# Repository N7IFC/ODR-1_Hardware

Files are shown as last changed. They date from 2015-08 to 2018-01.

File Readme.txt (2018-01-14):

This is the hardware repository for the ODR-1 (Open Design Radio - 1) which is a stand-alone "Firmware" defined QRP transceiver.The design goal for the radio is to cover from 1.8MHz (160 meters) up to 50 MHz (6 meters) though it may be able to cover up to 70MHz (4 meters).

The ODR-1 radio consists of the following circuit boards:

1) Display Board
2) Processor Board
3) Oscillator & Mixer Board
4) Amp and tuner board (not released, under design)

Each board hardware revision will have its own directory. When the circuit board layout changes significantly, there is a letter revision. If a minor revision occurs, such as a component value change or a cut and add, then a numeric suffix will be added to the letter revision. this allows older boards to be modified while not impacting the release of new board designs.

All schematic capture and layout is done with stable releases of KiCAD. You are encouraged to support the KiCAD development team as it is an outstanding collection of software.

Hardware - https://github.com/N7IFC/ODR-1_Hardware
Firmware - https://github.com/sylvanwilliams/ODR-1_Firmware

73s!

Bill N7IFC

This work is licensed under the Creative Commons Attribution-ShareAlike 4.0 International License.To view a copy of this license, visit http://creativecommons.org/licenses/by-sa/4.0/ or send a letter to Creative Commons, PO Box 1866, Mountain View, CA 94042, USA.

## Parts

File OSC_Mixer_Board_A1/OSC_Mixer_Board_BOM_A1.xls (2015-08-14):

Id | Designator | Package | Quantity | Designation | Description | MFR1 P/N | MFR1 Digikey P/N | MFR1 Mouser P/N | MFR1 Price | MFR1 Ext Price | MFR2 P/N | MFR2 Digikey P/N | MFR2 Price
1 | PCB |  | 1 |  | Bare Circuit Board |  |  |  | $75.00 | $75.00
2 | C17,C15 | SM0805-1 | 2 | 56pF | CAP CER 56PF 50V 5% NP0 0805 | C0805C560J5GACTU | 399-1118-1-ND |  | $0.10 | $0.20
3 | C79,C80 | SM0805-1 | 2 | 100pF | CAP CER 100PF 50V 5% NP0 0805 | CL21C101JBANNNC | 1276-1014-1-ND |  | $0.10 | $0.20
4 | C19,C23 | SM0805-1 | 2 | 120pF | CAP CER 120PF 50V 5% NP0 0805 | C0805C121J5GACTU | 399-1124-1-ND |  | $0.10 | $0.20
5 | C28,C24 | SM0805-1 | 2 | 130pF | CAP CER 130PF 100V 5% NP0 0805 | GRM2165C2A131JA01D | 490-1602-1-ND |  | $0.17 | $0.34
6 | C14, C18, C22,C20 | SM0805-1 | 4 | 150pF | CAP CER 150PF 50V 5% NP0 0805 | C0805C151J5GACTU | 399-1125-1-ND |  | $0.10 | $0.40
7 | C29,C33 | SM0805-1 | 2 | 180pF | CAP CER 180PF 50V 5% NP0 0805 | CL21C181JBANNNC | 1276-1129-1-ND |  | $0.11 | $0.22
8 | C27,C25 | SM0805-1 | 2 | 200pF | CAP CER 200PF 100V 5% NP0 0805 | GRM2165C2A201JA01D | 490-1606-1-ND |  | $0.17 | $0.34
9 | C21 | SM0805-1 | 1 | 220pF | CAP CER 220PF 50V 5% NP0 0805 | C0805C221J5GACTU | 399-1127-1-ND |  | $0.10 | $0.10
10 | C112,C113,C103,C106,C109,C110,C26,C34,C38 | SM0805-1 | 9 | 240pF | CAP CER 240PF 100V 5% NP0 0805 | GRM2165C2A241JA01D | 490-1608-1-ND |  | $0.14 | $1.27
11 | C16,C32,C30 | SM0805-1 | 3 | 300pF | CAP CER 300PF 50V 5% NP0 0805 | C0805C301J5GACTU | 399-9220-1-ND |  | $0.31 | $0.93
12 | C31,C39,C43 | SM0805-1 | 3 | 360pF | CAP CER 360PF 50V 5% NP0 0805 | C0805C361J5GACTU | 399-9230-1-ND |  | $0.31 | $0.93
13 | C37,C35 | SM0805-1 | 2 | 430pF | CAP CER 430PF 50V 5% NP0 0805 | CL21C431JBANNNC | 1276-2659-1-ND |  | $0.10 | $0.20
14 | C93,C94,C99,C98,C36 | SM0805-1 | 5 | 470pF | CAP CER 470PF 50V 5% NP0 0805 | CL21C471JBANNNC | 1276-1121-1-ND |  | $0.11 | $0.55
15 | C44,C48, C42,C40 | SM0805-1 | 4 | 620pF | CAP CER 620PF 50V 5% NP0 0805 | CL21C621JBCNNNC | 1276-2677-1-ND |  | $0.10 | $0.40
16 | C41 | SM0805-2 | 1 | 750pF | CAP CER 750PF 50V 5% NP0 0805 | C0805C751J5GACTU | 399-9271-1-ND |  | $0.37 | $0.37
17 | C47,C45,C49,C53 | SM0805-1 | 4 | 1100pF | CAP CER 1100PF 50V 5% NP0 0805 | GRM2165C1H112JA01D | 490-1623-1-ND |  | $0.18 | $0.72
18 | C46 | SM0805-1 | 1 | 1300pF | CAP CER 1300PF 50V 5% NP0 0805 | GRM2165C1H132JA01D | 490-1624-1-ND |  | $0.19 | $0.19
19 | C52,C50 | SM0805-1 | 2 | 2000pF | CAP CER 2000PF 100V 5% NP0 0805 | GRM2165C2A202JA01D | 490-6447-1-ND |  | $0.22 | $0.44
20 | C51 | SM0805-1 | 1 | 2200pF | CAP CER 2200PF 50V 5% NP0 0805 | CL21C222JBFNNNE | 1276-2993-1-ND |  | $0.17 | $0.17
21 | C102,C105 | SM0805-1 | 2 | 2400pF | CAP CER 2400PF 50V 5% NP0 0805 | GRM2165C1H242JA01D | 490-1629-1-ND |  | $0.22 | $0.44
22 | C73,C69,C66 | SM0805-1 | 3 | 0.01uF | CAP CER 10000PF 100V X7R 0805 | CL21B103KC65PNC | 1276-2440-1-ND |  | $0.10 | $0.30
23 | C96,C91,C97,C92 | SM0805-1 | 4 | 0.022uF | CAP CER 0.022UF 50V 5% C0G 0805 | CGA4J2C0G1H223J125AA | 445-6949-1-ND |  | $0.33 | $1.32
24 | C88,C87,C86,C83,C85,C57,C58,C114,C116,C115,C117,C118,C119,C120,C95,C100 | SM0805-1 | 16 | 0.033uF | CAP CER 0.033UF 100V 5% C0G 0805 | CGA4J1C0G2A333J125AC | 445-172691-1-ND |  | $0.33 | $5.28
25 | C77,C90,C89,C101,C104,C78,C71,C75,C81,C82,C76,C108,C107,C111,C5,C9,C1,C2,C11,C10,C12,C13,C64,C68,C67,C59,C60,C61,C62,C63,C54,C56 | SM0805-1 | 32 | 0.1uF | CAP CER 0.1UF 100V 10% X7R 0805 | CL21B104KCC5PNC | 1276-2447-1-ND |  | $0.11 | $3.52
26 | C70,C65 | SM0805-1 | 2 | 0.33uF | CAP CER 0.33UF 50V 10% X7R 0805 | CL21B334KBFNNNE | 1276-1123-1-ND |  | $0.18 | $0.36
27 | C8 | SM0805-1 | 1 | 1uF | CAP CER 1UF 50V 10% X7R 0805 | CL21B105KBFNNNE | 1276-1029-1-ND |  | $0.26 | $0.26
28 | C74,C72, C55 | SM0805-1 | 3 | 4.7uF | CAP CER 4.7UF 10V 10% X7R 0805 | CL21B475KPFNNNE | 1276-2972-1-ND |  | $0.20 | $0.60
29 | C4,C3,C6 | CAP_8.3X8.3 | 3 | 39uF | CAP POLYMER 39UF 20% 35V SMD | 35SVPF39M | P16561CT-ND |  | $1.68 | $5.04
30 | C84,C7 | CAP_8.3X8.3 | 2 | 270uF | CAP POLYMER 270UF 20% 16V SMD | 16SVPF270M | P16480CT-ND |  | $1.71 | $3.42
31 | D1 | DO-214AB(SMC) | 1 | SMCJ20CA | TVS DIODE 20VWM 32.4VC SMC | SMCJ20CA | SMCJ20CAFSCT-ND |  | $0.58 | $0.58
32 | D2 | DO-214AB(SMC) | 1 | SSC54-E3 | DIODE SCHOTTKY 40V 5A DO214AB | SSC54-E3/9AT | SSC54-E3/9ATGICT-ND |  | $0.63 | $0.63
33 | D10,D9,D8,D7,D6,D5,D4,D3 | SOD123 | 8 | 1N4148 | DIODE GEN PURP 100V 300MA SOD123 | 1N4148W-7-F | 1N4148W-FDICT-ND |  | $0.17 | $1.36
34 | FB1,FB2 | SM0805-1 | 2 | MPZ2012S101AT000 | FERRITE CHIP 100 OHM 4A 0805 | MPZ2012S101AT000 | 445-1567-1-ND |  | $0.12 | $0.24
35 | FB4,FB6,FB3,FB5 | SM0805-1 | 4 | MPZ2012S331A | FERRITE CHIP 330 OHM 2.5A 0805 | MPZ2012S331AT000 | 445-1569-1-ND |  | $0.12 | $0.48
36 | J1 | SIL-10 | 1 | FM-10 | CONN HEADER FMALE 10POS .1" GOLD | PPPC101LFBN-RC | S7043-ND |  | $0.84 | $0.84
37 | J2,J3,J4,J5,J6,J7 | SIL-12 | 6 | FM-12 | CONN HEADER FMALE 12POS .1" GOLD | PPPC121LFBN-RC | S7045-ND |  | $1.01 | $6.06
38 | J8 | PWR_JACK_5.5x2.1mm | 1 | PJ-057AH | CON PWR JCK 2.0 X 6.3MM HIGH CUR | PJ-057AH | CP-057AH-ND |  | $1.19 | $1.19
39 | L29,L35 | SM1210 | 2 | 0.033uH | FIXED IND 33NH 450MA 240 MOHM | NLV32T-033J-PF |  | 810-NLV32T-033J | $0.27 | $0.54
40 | L33,L32,L31,L30 | SM1210 | 4 | 0.056uH | FIXED IND 56NH 450MA 330 MOHM | NLV32T-056J-EF |  | 810-NLV32T-056J-EF | $0.27 | $1.08
41 | L1 | SM1210 | 1 | 0.082uH | FIXED IND 82NH 450MA 400 MOHM | NLV32T-082J-PF |  | 810-NLV32T-082J-PF | $0.27 | $0.27
42 | L28 | SM1210 | 1 | 0.10uH | FIXED IND 100NH 450MA 440 MOHM | NLV32T-R10J-PF |  | 810-NLV32T-R10J | $0.27 | $0.27
43 | L2 | SM1210 | 1 | 0.150uH | FIXED IND 150NH 450MA 250 MOHM | NLV32T-R15J-PF |  | 810-NLV32T-R15J | $0.27 | $0.27
44 | L3,L5,L4 | SM1210 | 3 | 0.22uH | FIXED IND 220NH 450MA 320 MOHM | NLV32T-R22J-PF |  | 810-NLV32T-R22J | $0.27 | $0.81
45 | L7,L8,L6 | SM1210 | 3 | 0.56uH | FIXED IND 560NH 450MA 550 MOHM | NLV32T-R56J-PF |  | 810-NLV32T-R56J-PF | $0.27 | $0.81
46 | L9,L11,L10 | SM1210 | 3 | 0.82uH | FIXED IND 820NH 450MA 650 MOHM | NLV32T-R82J-PF |  | 810-NLV32T-R82J-PF | $0.27 | $0.81
47 | L12,L14,L13 | SM1210 | 3 | 1.2uH | FIXED IND 1.2UH 390MA 750 MOHM | NLV32T-1R2J-PF |  | 810-NLV32T-1R2J-PF | $0.27 | $0.81
48 | L16,L17,L15 | SM1210 | 3 | 1.8uH | FIXED IND 1.8UH 350MA 900 MOHM | NLV32T-1R8J-PF |  | 810-NLV32T-1R8J-PF | $0.27 | $0.81
49 | L19,L20,L18 | SM1210 | 3 | 2.7uH | FIXED IND 2.7UH 290MA 1.1 OHM | NLV32T-2R7J-PF |  | 810-NLV32T-2R7J-PF | $0.27 | $0.81
50 | L22,L23,L21 | SM1210 | 3 | 3.9uH | FIXED IND 3.9UH 250MA 1.3 OHM | NLV32T-3R9J-PF |  | 810-NLV32T-3R9J-PF | $0.27 | $0.81
51 | L25,L26,L24 | SM1210 | 3 | 8.2uH | FIXED IND 8.2UH 170MA 2 OHM SMD | NLV32T-8R2J-PF |  | 810-NLV32T-8R2J-PF | $0.27 | $0.81
52 | L34,L27 | SM1210 | 2 | 33uH | FIXED IND 33UH 95MA 650 MOHM SMD | NLFV32T-330K-EF | 445-15768-1-ND |  | $0.43 | $0.86
53 | L43,L42,L41,L40,L36,L37,L38,L39 | SM1210 | 8 | 47uH | FIXED IND 47UH 90MA 850 MOHM SMD | NLFV32T-470K-EF |  | 810-NLFV32T-470K-EFT | $0.43 | $3.44
54 | Q1 | SOT23 | 1 | IRLML2060TRPBF | MOSFET N-CH 60V 1.2A SOT23-3 | IRLML2060TRPBF | IRLML2060TRPBFCT-ND |  | $0.36 | $0.36
55 | Q2 | SO8N-1 | 1 | DMP4015SSSQ | MOSFET P-CH 40V 9.1A SO-8 | DMP4015SSSQ-13 | DMP4015SSSQ-13DICT-ND |  | $0.62 | $0.62
56 | Q3 | SOT23 | 1 | BFU520A | TRANS RF NPN 12V 30MA SOT23-3 | BFU520AR | 568-11503-1-ND |  | $0.54 | $0.54
57 | R15 | SM0805-1 | 1 | 2.21 | RES SMD 2.21 OHM 1% 1/8W 0805 | RC0805FR-072R21L | 311-2.21CRCT-ND |  | $0.10 | $0.10
58 | R18,R19 | SM0805-1 | 2 | 10 | RES SMD 10 OHM 1% 1/8W 0805 | ERJ-6ENF10R0V | P10.0CCT-ND |  | $0.10 | $0.20
59 | R22,R23 | SM0805-1 | 2 | 17.4 | RES SMD 17.4 OHM 0.1% 1/4W 0805 | 5-1625868-0 | A110374CT-ND |  | $0.76 | $1.52
60 | R51,R31,R34,R38,R41,R42,R45,R48,R7 | SM0805-1 | 9 | 30.1 | RES SMD 30.1 OHM 0.1% 1/4W 0805 | 7-1625868-3 | A110397CT-ND |  | $0.54 | $4.89
61 | R9,R11 | SM0805-1 | 2 | 52.3 | RES SMD 52.3 OHM 1% 1/8W 0805 | ERJ-6ENF52R3V | P52.3CCT-ND |  | $0.10 | $0.20
62 | R16 | SM0805-1 | 1 | 68.1 | RES SMD 68.1 OHM 1% 1/8W 0805 | ERJ-6ENF68R1V | P68.1CCT-ND |  | $0.10 | $0.10
63 | R25,R27,R26,R24 | SM0805-1 | 4 | 97.6 | RES SMD 97.6 OHM 1% 1/8W 0805 | ERJ-6ENF97R6V | P97.6CCT-ND |  | $0.10 | $0.40
64 | R50,R53,R44,R47 | SM0805-1 | 4 | 100 | RES SMD 100 OHM 1% 1/8W 0805 | ERJ-6ENF1000V | P100CCT-ND |  | $0.10 | $0.40
65 | R6,R8 | SM0805-1 | 2 | 147 | RES SMD 147 OHM 1% 1/8W 0805 | ERJ-6ENF1470V | P147CCT-ND |  | $0.10 | $0.20
66 | R10 | SM0805-1 | 1 | 332 | RES SMD 332 OHM 1% 1/8W 0805 | ERJ-6ENF3320V | P332CCT-ND |  | $0.10 | $0.10
67 | R14 | SM0805-1 | 1 | 374 | RES SMD 374 OHM 1% 1/8W 0805 | ERJ-6ENF3740V | P374CCT-ND |  | $0.10 | $0.10
68 | R17 | SM0805-1 | 1 | 470 | RES SMD 470 OHM 1% 1/8W 0805 | ERJ-6ENF4700V | P470CCT-ND |  | $0.10 | $0.10
69 | R21,R20,R12 | SM0805-1 | 3 | 1.00K | RES SMD 1K OHM 1% 1/8W 0805 | ERJ-6ENF1001V | P1.00KCCT-ND |  | $0.10 | $0.30
70 | R29,R36 | SM0805-1 | 2 | 1.50K | RES SMD 1.5K OHM 1% 1/8W 0805 | ERJ-6ENF1501V | P1.50KCCT-ND |  | $0.10 | $0.20
71 | R5 | SM0805-1 | 1 | 2.61K | RES SMD 2.61K OHM 1% 1/8W 0805 | ERJ-6ENF2611V | P2.61KCCT-ND |  | $0.10 | $0.10
72 | R52,R49,R43,R46 | SM0805-1 | 4 | 3.01K | RES SMD 3.01K OHM 0.1% 1/4W 0805 | 5-2176092-8 | A110589CT-ND |  | $0.76 | $3.04
73 | R13 | SM0805-1 | 1 | 3.74K | RES SMD 3.74K OHM 1% 1/8W 0805 | ERJ-6ENF3741V | P3.74KCCT-ND |  | $0.10 | $0.10
74 | R4 | SM0805-1 | 1 | 4.64K | RES SMD 4.64K OHM 1% 1/8W 0805 | ERJ-6ENF4641V | P4.64KCCT-ND |  | $0.10 | $0.10
75 | R1,R2 | SM0805-1 | 2 | 4.75K | RES SMD 4.75K OHM 1% 1/8W 0805 | ERJ-6ENF4751V | P4.75KCCT-ND |  | $0.10 | $0.20
76 | R28,R35,R33,R32,R40,R39 | SM0805-1 | 6 | 9.31K | RES SMD 9.31K OHM 1% 1/8W 0805 | ERJ-6ENF9311V | P9.31KCCT-ND |  | $0.10 | $0.60
77 | R3 | SM0805-1 | 1 | 10.0K | RES SMD 10K OHM 1% 1/8W 0805 | ERJ-6ENF1002V | P10.0KCCT-ND |  | $0.10 | $0.10
78 | R30,R37 | SM0805-1 | 2 | 18.7K | RES SMD 18.7K OHM 1% 1/8W 0805 | ERJ-6ENF1872V | P18.7KCCT-ND |  | $0.10 | $0.20
79 | T1 | SM-22 | 1 | ETC1-1T-2TR | XFMR 0.1-200MHZ 1:1 SMD | ETC1-1T-2TR |  | 937-ETC1-1T-2 | $2.61 | $2.61
80 | U1 | DPAK2 | 1 | L78M05AB | IC REG LDO 5V 0.5A DPAK | L78M05ABDT-TR | 497-1201-1-ND |  | $0.64 | $0.64
81 | U6 | TSOP-5 | 1 | NCP700BSN18 | IC REG LDO 1.8V 0.2A 5TSOP | NCP700BSN18T1G | NCP700BSN18T1GOSCT-ND |  | $0.72 | $0.72
82 | U9 | TSOP-5 | 1 | NCP700BSN33 | IC REG LDO 3.3V 0.2A 5TSOP | NCP700BSN33T1G | NCP700BSN33T1GOSCT-ND |  | $0.72 | $0.72
83 | U10 | SOT323-5L | 1 | STLM20W87F | SENSOR TEMP RATIOMETRIC SOT323-5 | STLM20W87F | 497-5970-1-ND |  | $0.92 | $0.92
84 | U11 | MSOP_10 | 1 | SI5351A | IC CLK GENERATOR 160MHZ 10MSOP | SI5351A-B-GT | 336-2399-5-ND |  | $1.16 | $1.16
85 | U12,U13 | US8 | 2 | NC7SZ74 | IC D-TYPE POS TRG SNGL US8 | NC7SZ74K8X | NC7SZ74K8XCT-ND |  | $0.49 | $0.98
86 | U17,U16 | SO8N-1 | 2 | TLV2462CD | IC OPAMP GP 6.4MHZ RRO 8SOIC | TLV2462CDR | 296-2434-1-ND |  | $2.37 | $4.74
87 | U20,U19 | SO8N-1 | 2 | LT6231 | IC OPAMP GP 215MHZ RRO 8SO | LT6231CS8#PBF | LT6231CS8#PBF-ND |  | $3.89 | $7.78
88 | U18,U15,U14 | SO16S | 3 | FST3257 | MUX/DEMUX QUAD 2:1 TTL 16SOIC | FST3257MX | FST3257MXFSCT-ND |  | $0.67 | $2.01
89 | U8,U7,U4,U5,U3,U2 | SO16S | 6 | FST3253 | MUX/DEMUX DUAL 4:1 TTL 16SOIC | FST3253MX | FST3253MXFSCT-ND |  | $0.65 | $3.90
90 | X1 | CRYSTAL_4 | 1 | 25 MHz | Crystal 25.0000MHz 10ppm 8pF 50 Ohm -20°C - 70°C Surface Mount 4-SMD, No Lead (DFN, LCC) | CX3225SB25000D0FFFCC | 1253-1353-1-ND |  | $0.76 | $0.76
 |  |  |  |  |  |  |  |  |  | $170.01

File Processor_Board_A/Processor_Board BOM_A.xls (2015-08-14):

Id | Designator | Package | Quantity | Designation | Description | MFR1 P/N | MFR1 Digikey P/N | MFR1 Mouser P/N | MFR1 Price | MFR1 Ext Price | MFR2 P/N | MFR2 Digikey P/N | MFR2 Price
1 | C52,C51, C91,C94 | SM0805-1 | 4 | 6pF | CAP CER 6PF 50V NP0 0805 | CL21C060CBANNNC | 1276-1767-1-ND |  | $0.10 | $0.40
2 | C98,C80,C49,C50 | SM0805-1 | 4 | 15pF | CAP CER 15PF 50V 5% NP0 0805 | 08055A150JAT2A | 478-1306-1-ND |  | $0.15 | $0.60
3 | C31,C32,C104,C77,C79,C76,C78 | SM0805-1 | 7 | 1000pF | CAP CER 1000PF 250V 5% C0G 0805 | C2012C0G2E102J085AA | 445-2325-1-ND |  | $0.13 | $0.91
4 | C26,C23,C20,C17,C14,C12,C10,C8,C37,C22,C25,C16,C19,C6,C28,C29,C3,C2,C1,C4,C30,C27,C24,C21,C36,C18,C15,C13,C11,C9,C7,C5,C75,C73,C74 | SM0805-1 | 35 | 0.01uF | CAP CER 10000PF 100V X7R 0805 | CL21B103KC65PNC | 1276-2440-1-ND |  | $0.04 | $1.37
5 | C45,C47,C33,C43,C84,C86,C88,C89,C90,C97,C99,C66,C61,C54,C63,C71,C72,C39,C44,C40,C41,C42,C67,C53 | SM0805-1 | 24 | 0.1uF | CAP CER 0.1UF 100V 10% X7R 0805 | CL21B104KCC5PNC | 1276-2447-1-ND |  | $0.06 | $1.32
6 | C58,C57,C55,C56 | SM0805-1 | 4 | 0.22uF | CAP CER 0.22UF 50V 10% X7R 0805 | C0805C224K5RACTU | 399-3491-1-ND |  | $0.14 | $0.56
7 | C103,C87 | SM0805-1 | 2 | 0.47uF | CAP CER 0.47UF 50V 10% X7R 0805 | CC0805KKX7R9BB474 | 311-1889-1-ND |  | $0.24 | $0.48
8 | C35,C92,C60,C59,C96 | SM1206-1 | 5 | 1uF | CAP CER 1UF 50V 10% X7R 1206 | C3216X7R1H105K160AB | 445-1423-1-ND |  | $0.17 | $0.83 | CL31B105KBHNNNE |  | $0.17
9 | C102,C85 | SM1206-1 | 2 | 2.2uF | CAP CER 2.2UF 50V 10% X7R 1206 | CL31B225KBHNNNE | 1276-1291-1-ND |  | $0.25 | $0.50
10 | C95,C81,C101,C105,C106,C38,C34,C93,C83 | SM1206-1 | 9 | 4.7uF | CAP CER 4.7UF 50V 10% X7R 1206 | UMK316AB7475KL-T | 587-2994-1-ND |  | $0.19 | $1.71 | CL31B475KBHNNNE |  | $0.28
11 | C46,C62,C65,C48 | SM1206-1 | 4 | 10uF | CAP CER 10UF 25V 10% X5R 1206 | CL31A106KAHNNNE | 1276-1075-1-ND |  | $0.24 | $0.96
12 | C100,C64,C70 | SM1206-1 | 3 | 22uF | CAP CER 22UF 16V 10% X5R 1206 | CL31A226KOCLFNC | 1276-2725-1-ND |  | $0.43 | $1.29
13 | C82,C69,C68,C107 | SM1206-1 | 4 | 47uF | CAP CER 47UF 10V 20% X5R 1206 | C1206C476M8PACTU | 399-5508-1-ND |  | $0.67 | $2.68
14 | D1 | SOD123F | 1 | 1A_30V_SCH | DIODE SCHOTTKY 30V 1A MINI2 | DB2X41100L | DB2X41100LCT-ND |  | $0.44 | $0.44 | CRS01(TE85L,Q,M) |  | $0.44
15 | D2 | SOT23-1 | 1 | LM4040C25 | IC VREF SHUNT 2.5V SOT23-3 | LM4040C25FTA | LM4040C25FCT-ND |  | $0.71 | $0.71
16 | D3 | SM_LED_RA | 1 | GRN | LED 2.1X0.6MM 570NM GRN RA SMD | APA2106CGCK | 754-1057-1-ND |  | $0.49 | $0.49
17 | FB14,FB9,FB10,FB8,FB11 | SM0805-1 | 5 | MMZ2012R102A | FERRITE CHIP 1000 OHM 500MA 0805 | MMZ2012R102AT000 | 445-1555-1-ND |  | $0.09 | $0.44
18 | FB5,FB1,FB4,FB3,FB2,FB6,FB15,FB13,FB12,FB7 | SM0805-1 | 10 | MPZ2012S102A | FERRITE CHIP 1000 OHM 1.5A 0805 | MPZ2012S102AT000 | 445-5223-1-ND |  | $0.10 | $1.01
19 | J10 | USB_MICRO_AB | 1 | USB_MICRO_AB | Connector Receptacle USB micro AB 5 Position Surface Mount, Right Angle, Horizontal | 475890001 | WM17143CT-ND |  | $0.81 | $0.81 | ZX62D-AB-5P8 |  | $1.31
20 | J11,J13,J14,J15 | AUDIO-5 | 4 | JACK_5P | CONN JACK STEREO R/A 3PIN 3.5MM | SJ1-3513 | CP1-3513-ND |  | $1.71 | $6.84 | 35RAPC2BH3 |  | $1.98
21 | J16 | RJ45-8LP | 1 | RJ45_LP_UNS | CONN MOD JACK 8P8C R/A UNSHLD | A-2004-2-4-LP-N-R | AE10384-ND |  | $0.69 | $0.69 | RJE051880310 |  | $1.36
22 | J9 | HDR_8x2_RA | 1 | CONN_8X2 | Connector Header 16 Position 0.100" (2.54mm) Gold Through Hole, Right Angle | PPPC082LJBN-RC | S5561-ND |  | $1.64 | $1.64
23 | L1 | SM2233 | 1 | 10uH | FIXED IND 10UH 3.1A 44.2 MOHM | NR8040T100M | 587-2001-1-ND |  | $0.50 | $0.50
24 | L2 | SM2233 | 1 | 22uH | FIXED IND 22UH 2.2A 85.8 MOHM | NR8040T220M | 587-2002-1-ND |  | $0.50 | $0.50
25 | P1 | SIL-10-1 | 1 | M-10 | CONN HEADER .100" SNGL STR 10POS 0.230L | PRPC010SAAN-RC | S1011EC-10-ND |  | $0.30 | $0.30
26 | P12 | SIL-6_RA | 1 | CONN_6 | CONN HEADER .100" SNGL R/A 6POS 0.230L | PRPC006SBAN-M71RC | S1111EC-06-ND |  | $0.29 | $0.29
27 | P7,P3,P5 | SIL-12-1 | 3 | M-12 | CONN HEADER .100" SNGL STR 12POS 0.230L | PRPC012SAAN-RC | S1011EC-12-ND |  | $0.33 | $0.99
28 | Q2,Q1 | SOT23-1 | 2 | IRLML2060TRPBF | MOSFET N-CH 60V 1.2A SOT23-3 | IRLML2060TRPBF | IRLML2060TRPBFCT-ND |  | $0.36 | $0.72
29 | R38,R25,R9,R1,R2,R10,R11,R64 | SM0805-1 | 8 | 22.1 | RES SMD 22.1 OHM 1% 1/8W 0805 | ERJ-6ENF22R1V | P22.1CCT-ND |  | $0.10 | $0.80
30 | R69,R67,R70,R68 | SM0805-1 | 4 | 49.9 | RES SMD 49.9 OHM 1% 1/8W 0805 | ERJ-6ENF49R9V | P49.9CCT-ND |  | $0.10 | $0.40
31 | R76,R80,R75,R74 | SM0805-1 | 4 | 75 | RES SMD 75 OHM 1% 1/8W 0805 | ERJ-6ENF75R0V | P75.0CCT-ND |  | $0.10 | $0.40
32 | R52 | SM0805-1 | 1 | 100 | RES SMD 100 OHM 1% 1/8W 0805 | ERJ-6ENF1000V | P100CCT-ND |  | $0.10 | $0.10
33 | R48,R18,R33,R19,R32,R43,R31,R42,R30,R41,R29,R28,R40,R27,R39,R26,R24,R37,R23,R36,R22,R35,R21,R34,R20,R53 | SM0805-1 | 26 | 220 | RES SMD 220 OHM 1% 1/8W 0805 | ERJ-6ENF2200V | P220CCT-ND |  | $0.02 | $0.57
34 | R66 | SM0805-1 | 1 | 270 | RES SMD 270 OHM 1% 1/8W 0805 | ERJ-6ENF2700V | P270CCT-ND |  | $0.10 | $0.10
35 | R47,R46,R79,R77 | SM0805-1 | 4 | 1.00K | RES SMD 1K OHM 1% 1/8W 0805 | ERJ-6ENF1001V | P1.00KCCT-ND |  | $0.10 | $0.40
36 | R50 | SM0805-1 | 1 | 1.91K | RES SMD 1.91K OHM 1% 1/8W 0805 | ERJ-6ENF1911V | P1.91KCCT-ND |  | $0.10 | $0.10
37 | R63 | SM0805-1 | 1 | 2.32K | RES SMD 2.32K OHM 1% 1/8W 0805 | ERJ-6ENF2321V | P2.32KCCT-ND |  | $0.10 | $0.10
38 | R56 | SM0805-1 | 1 | 2.70K | RES SMD 2.70K OHM 1% 1/8W 0805 | ERJ-6ENF2701V | P2.70KCCT-ND |  | $0.10 | $0.10
39 | R51 | SM0805-1 | 1 | 4.75K | RES SMD 4.75K OHM 1% 1/8W 0805 | ERJ-6ENF4751V | P4.75KCCT-ND |  | $0.10 | $0.10
40 | R16,R15,R14,R13,R12,R8,R7,R6,R5,R4,R17,R3,R44,R45,R55,R78,R59,R60,R58,R57 | SM0805-1 | 20 | 10.0K | RES SMD 10K OHM 1% 1/8W 0805 | ERJ-6ENF1002V | P10.0KCCT-ND |  | $0.10 | $2.00
41 | R49 | SM0805-1 | 1 | 13.7K | RES SMD 13.7K OHM 1% 1/8W 0805 | ERJ-6ENF1372V | P13.7KCCT-ND |  | $0.10 | $0.10
42 | R65,R73 | SM0805-1 | 2 | 40.2K | RES SMD 40.2K OHM 1% 1/8W 0805 | ERJ-6ENF4022V | P40.2KCCT-ND |  | $0.10 | $0.20
43 | R81 | SM0805-1 | 1 | 100K | RES SMD 100K OHM 1% 1/8W 0805 | ERJ-6ENF1003V | P100KCCT-ND |  | $0.10 | $0.10
44 | R72 | SM0805-1 | 1 | 249K | RES SMD 249K OHM 1% 1/8W 0805 | ERJ-6ENF2493V | P249KCCT-ND |  | $0.10 | $0.10
45 | R62 | SM0805-1 | 1 | 432K | RES SMD 432K OHM 1% 1/8W 0805 | ERJ-6ENF4323V | P432KCCT-ND |  | $0.10 | $0.10
46 | R71,R61 | SM0805-1 | 2 | 1M | RES SMD 1M OHM 1% 1/8W 0805 | ERJ-6ENF1004V | P1.00MCCT-ND |  | $0.10 | $0.20
47 | T1 | XFMR_ETH16 | 1 | TRANSFO_ETHER | MODULE XFRMR LAN 10/100 POE SMD | S558-5500-25-F | 507-1724-1-ND |  | $2.48 | $2.48 | 749010013 |  | $2.14
48 | U2 | TQFP_100_14MM | 1 | DSPIC33EP512MU810-I/PF | IC DSC 16BIT 512KB FLASH 100TQFP 14MM | DSPIC33EP512MU810-I/PF | DSPIC33EP512MU810-I/PF-ND |  | $10.75 | $10.75
49 | U3 | SO8N-1 | 1 | M95256 | IC EEPROM 256KBIT 20MHZ 8SOIC | M95256-DFMN6TP | 497-15776-1-ND |  | $1.23 | $1.23
50 | U4 | VQFN32 | 1 | TLV320AIC3204 | IC STEREO AUDIO CODEC 1.8V 32QFN | TLV320AIC3204IRHBT | 296-32391-1-ND |  | $6.55 | $6.55
51 | U5,U1 | SOT23-6L | 2 | TVS_ARRAY_4CH | TVS DIODE 5.25VWM 17VC SOT23-6 | USBLC6-4SC6 | 497-4492-1-ND |  | $0.44 | $0.88
52 | U6 | SSOP28-1 | 1 | ENC28J60-I/SS | IC ETHERNET CTRLR W/SPI 28SSOP | ENC28J60-I/SS | ENC28J60-I/SS-ND |  | $3.35 | $3.35
53 | U7 | PWRPAD16 | 1 | LM43601 | IC REG BUCK ADJ 1A SYNC 16SSOP | LM43601PWPR | 296-40221-1-ND |  | $4.15 | $4.15
54 | U8 | PWRPAD16 | 1 | LM43600 | IC REG BUCK ADJ 0.5A SYNC 16SSOP | LM43600PWPR | 296-40220-1-ND |  | $3.89 | $3.89
55 | X1 | CRYSTAL_4L | 1 | 32.768 KHz | Crystal 32.7680kHz 20ppm 12.5pF 65 kOhm -40°C - 85°C Surface Mount 2-SMD | 9HT7-32.768KDZF-T | 887-1860-1-ND |  | $0.44 | $0.44 | CM13032768DZFT |  | $0.52
56 | X2 | CRYSTAL_4 | 1 | 12.000 MHz | Crystal 12.0000MHz 10ppm 8pF 150 Ohm -20°C - 70°C Surface Mount 4-SMD, No Lead (DFN, LCC) | CX3225SB12000D0FFJCC | 1253-1350-1-ND |  | $0.76 | $0.76
57 | X3 | CRYSTAL_4 | 1 | 25MHz | Crystal 25.0000MHz 10ppm 8pF 50 Ohm -20°C - 70°C Surface Mount 4-SMD, No Lead (DFN, LCC) | CX3225SB25000D0FFFCC | 1253-1353-1-ND |  | $0.76 | $0.76 | NX3225SA-25.000M-STD-CSR-3
 |  |  |  |  |  |  |  |  |  | $71.19

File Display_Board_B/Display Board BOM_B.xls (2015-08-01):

Id | Designator | Package | Quantity | Designation | Description | MFR1 P/N | MFR1 Digikey P/N | MFR1 Mouser P/N | MFR1 Price | MFR1 Ext Price | MFR2 P/N | MFR2 Digikey P/N | MFR2 Price
1 | C201 | SM0805-1 | 1 | 0.1uF | CAP CER 0.1UF 100V 10% X7R 0805 | CL21B104KCC5PNC | 1276-2447-1-ND |  | $0.06 | $0.06
2 | C200 | SM1206-1 | 1 | 22uF | CAP CER 22UF 16V 10% X5R 1206 | CL31A226KOCLFNC | 1276-2725-1-ND |  | $0.43 | $0.43
3 | EN200,EN201 | ROTARY_ENCODER_1 | 2 | PEC16-4 | ENCODER ROTARY, 12 DETENT PLUS SWX | PEC16-4220F-S0012 | PEC16-4220F-S0012-ND |  | $1.38 | $2.76
4 | FB200 | SM0805-1 | 1 | MPZ2012S102A | FERRITE CHIP 1000 OHM 1.5A 0805 | MPZ2012S102AT000 | 445-5223-1-ND |  | $0.10 | $0.10
5 | KN200,KN201 |  | 2 |  | KNOB BLK/MATTE.625"DIA 6MM SHAFT | OEJA-63-4-7 | 226-4129-ND |  | $5.45 | $10.90 | OEDA-63-4-7 |  | $5.450
6 | P9 | HDR_8x2 | 1 | CONN_8X2 | CONN HEADER .100" DUAL STR 16POS | PRPC008DAAN-RC | S2011EC-08-ND |  | $0.53 | $0.53
7 | Q200 | SOT23 | 1 | IRLML2060TRPBF | MOSFET N-CH 60V 1.2A SOT23-3 | IRLML2060TRPBF | IRLML2060TRPBFCT-ND |  | $0.36 | $0.36
8 | R200,R201,R202,R203 | SM0805-1 | 4 | 4.75 | RES SMD 4.75 OHM 1% 1/8W 0805 | RMCF0805FT4R75 | RMCF0805FT4R75CT-ND |  | $0.10 | $0.40
9 | R204 | SM0805-1 | 1 | 10 | RES SMD 10 OHM 1% 1/8W 0805 | ERJ-6ENF10R0V | P10.0CCT-ND |  | $0.10 | $0.10
10 | R205 | SM0805-1 | 1 | 10.0K | RES SMD 10K OHM 1% 1/8W 0805 | ERJ-6ENF1002V | P10.0KCCT-ND |  | $0.10 | $0.10
11 | U200 | TM022HDH26 | 1 | LCD__TM022HDH26 | LCD DISPLAY 320X240 SPI ILI9341 TIANMA | TM022HDH26 |  |  | $6.70 | $6.70
 |  |  |  |  |  |  |  |  |  | $22.44

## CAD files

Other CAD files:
Drawings/2015001 ODR-1 Mechanical_A.dwg

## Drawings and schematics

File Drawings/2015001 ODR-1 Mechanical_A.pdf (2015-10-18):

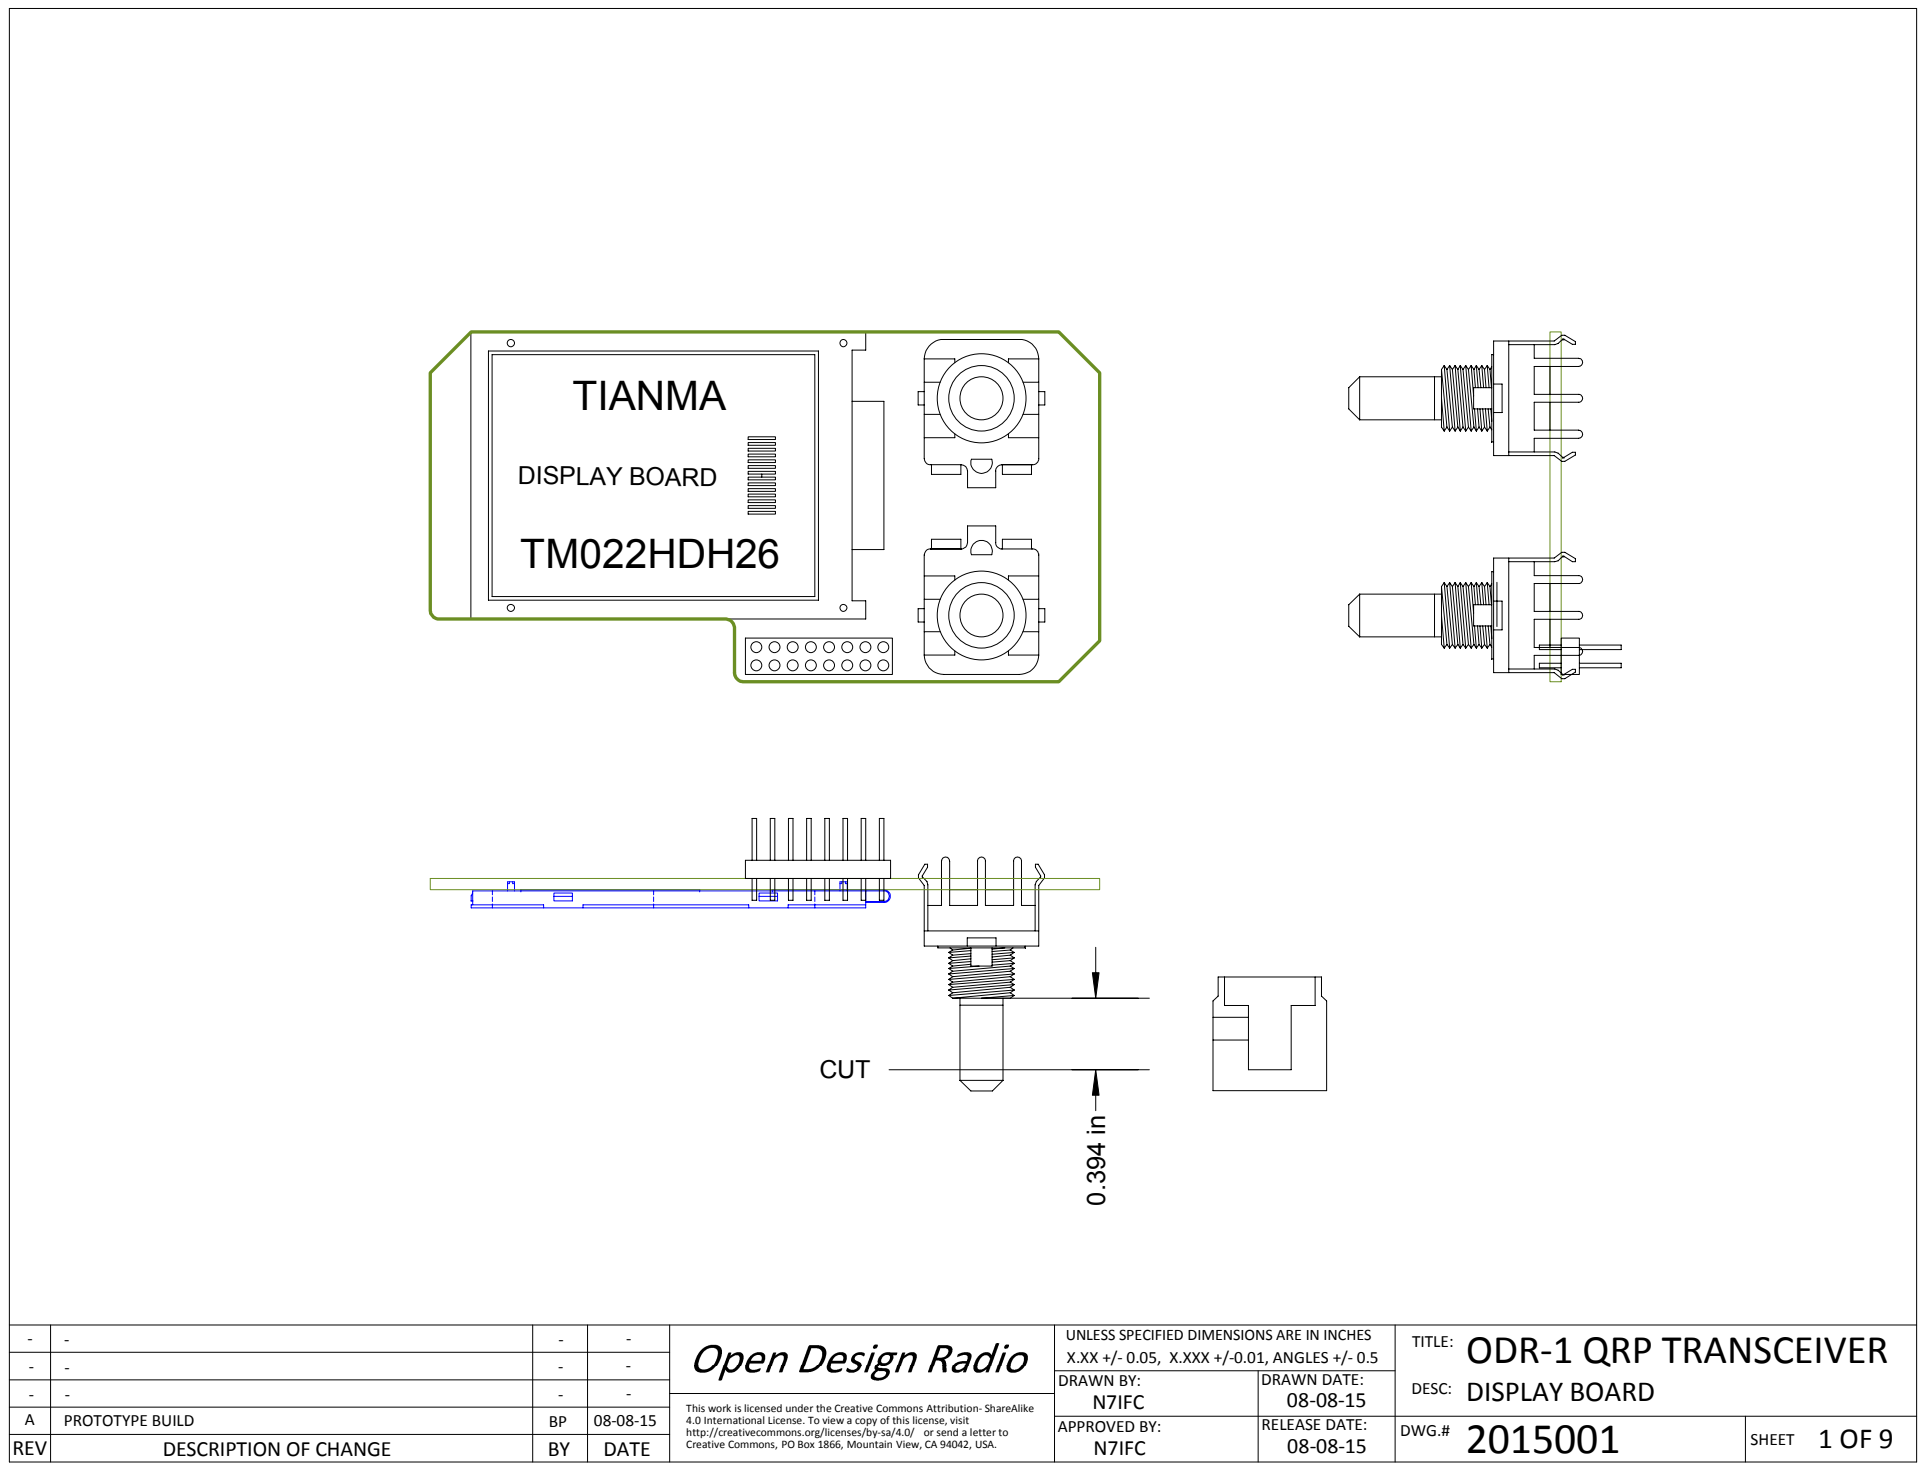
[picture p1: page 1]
REV; DESCRIPTION OF CHANGE; DATE; DRAWN BY:; DESC:; RELEASE DATE:; DWG.#; DRAWN DATE:; TITLE:; SHEET; Creative Commons, PO Box 1866, Mountain View, CA 94042, USA.; N7IFC; PROTOTYPE BUILD; - TIANMA TM022HDH26 DISPLAY BOARD; CUT

UNLESS SPECIFIED DIMENSIONS ARE IN INCHES
X.XX +/- 0.05, X.XXX +/-0.01, ANGLES +/- 0.5
APPROVED BY:

ODR-1 QRP TRANSCEIVER
DISPLAY BOARD

This work is licensed under the Creative Commons Attribution- ShareAlike
4.0 International License. To view a copy of this license, visit
http://creativecommons.org/licenses/by-sa/4.0/ or send a letter to

# PHONE ETHERNET

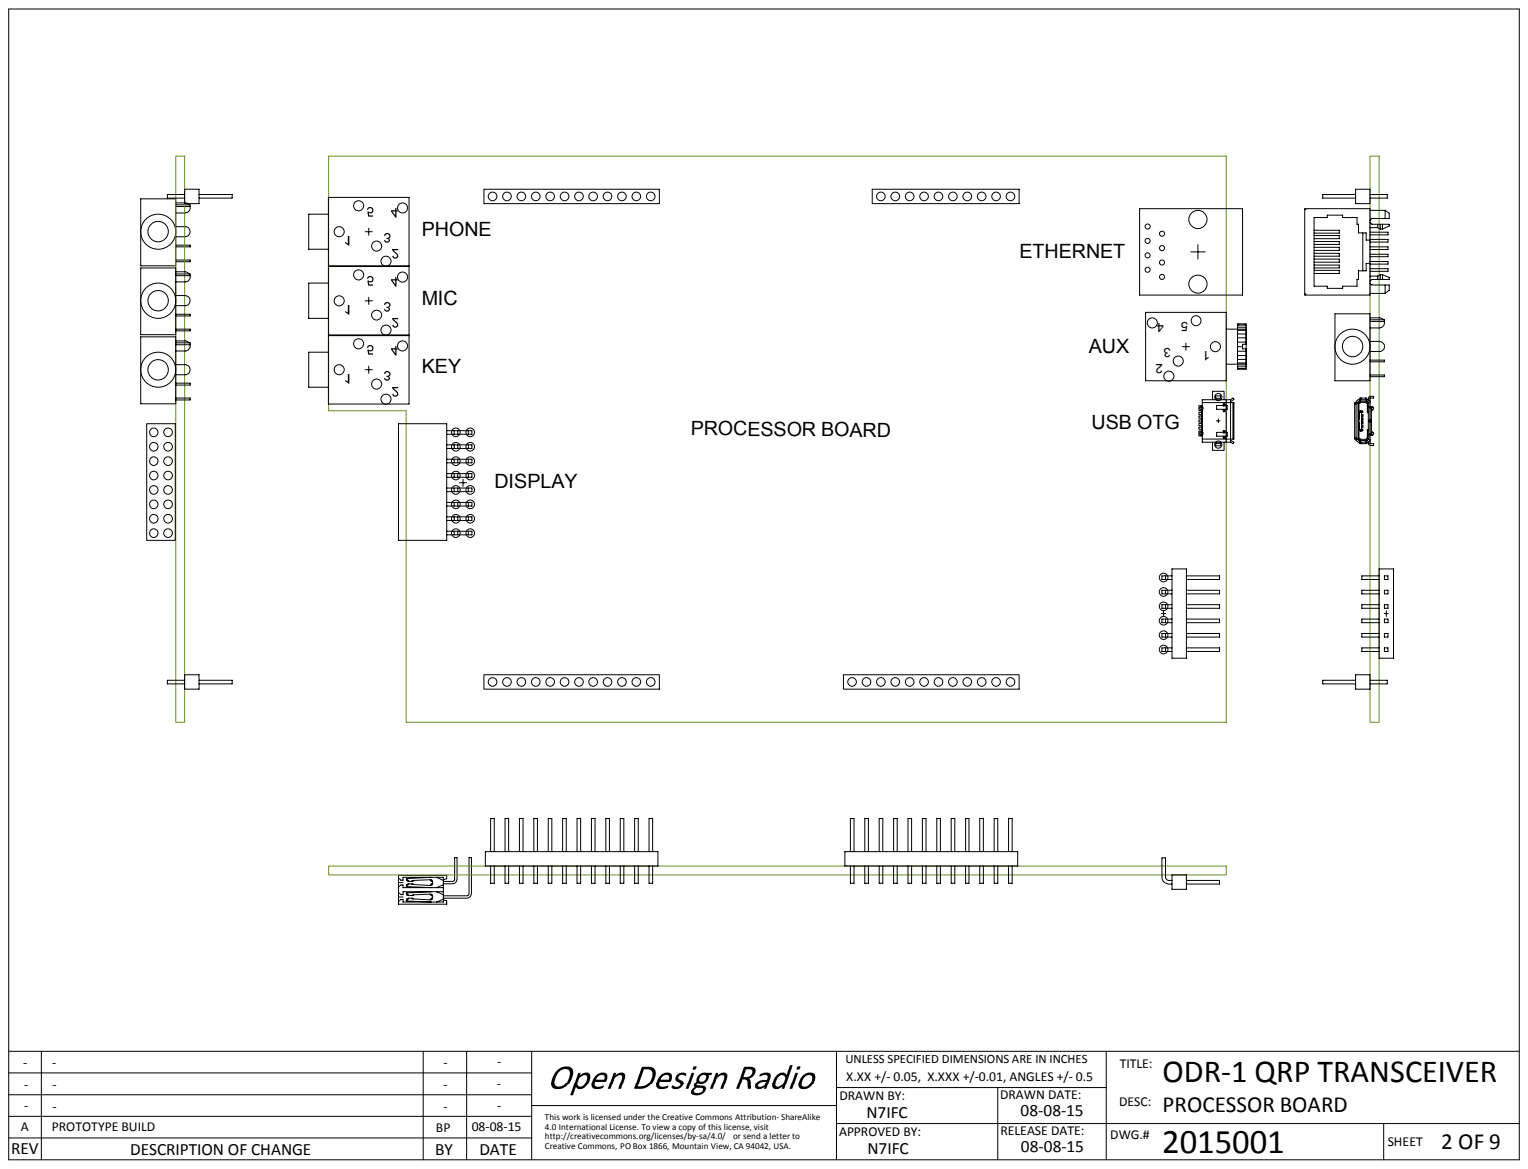
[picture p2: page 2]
TITLE:; PROTOTYPE BUILD; PROCESSOR BOARD; MIC; KEY; AUX; USB OTG; DISPLAY

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

ODR-1 QRP TRANSCEIVER
PROCESSOR BOARD

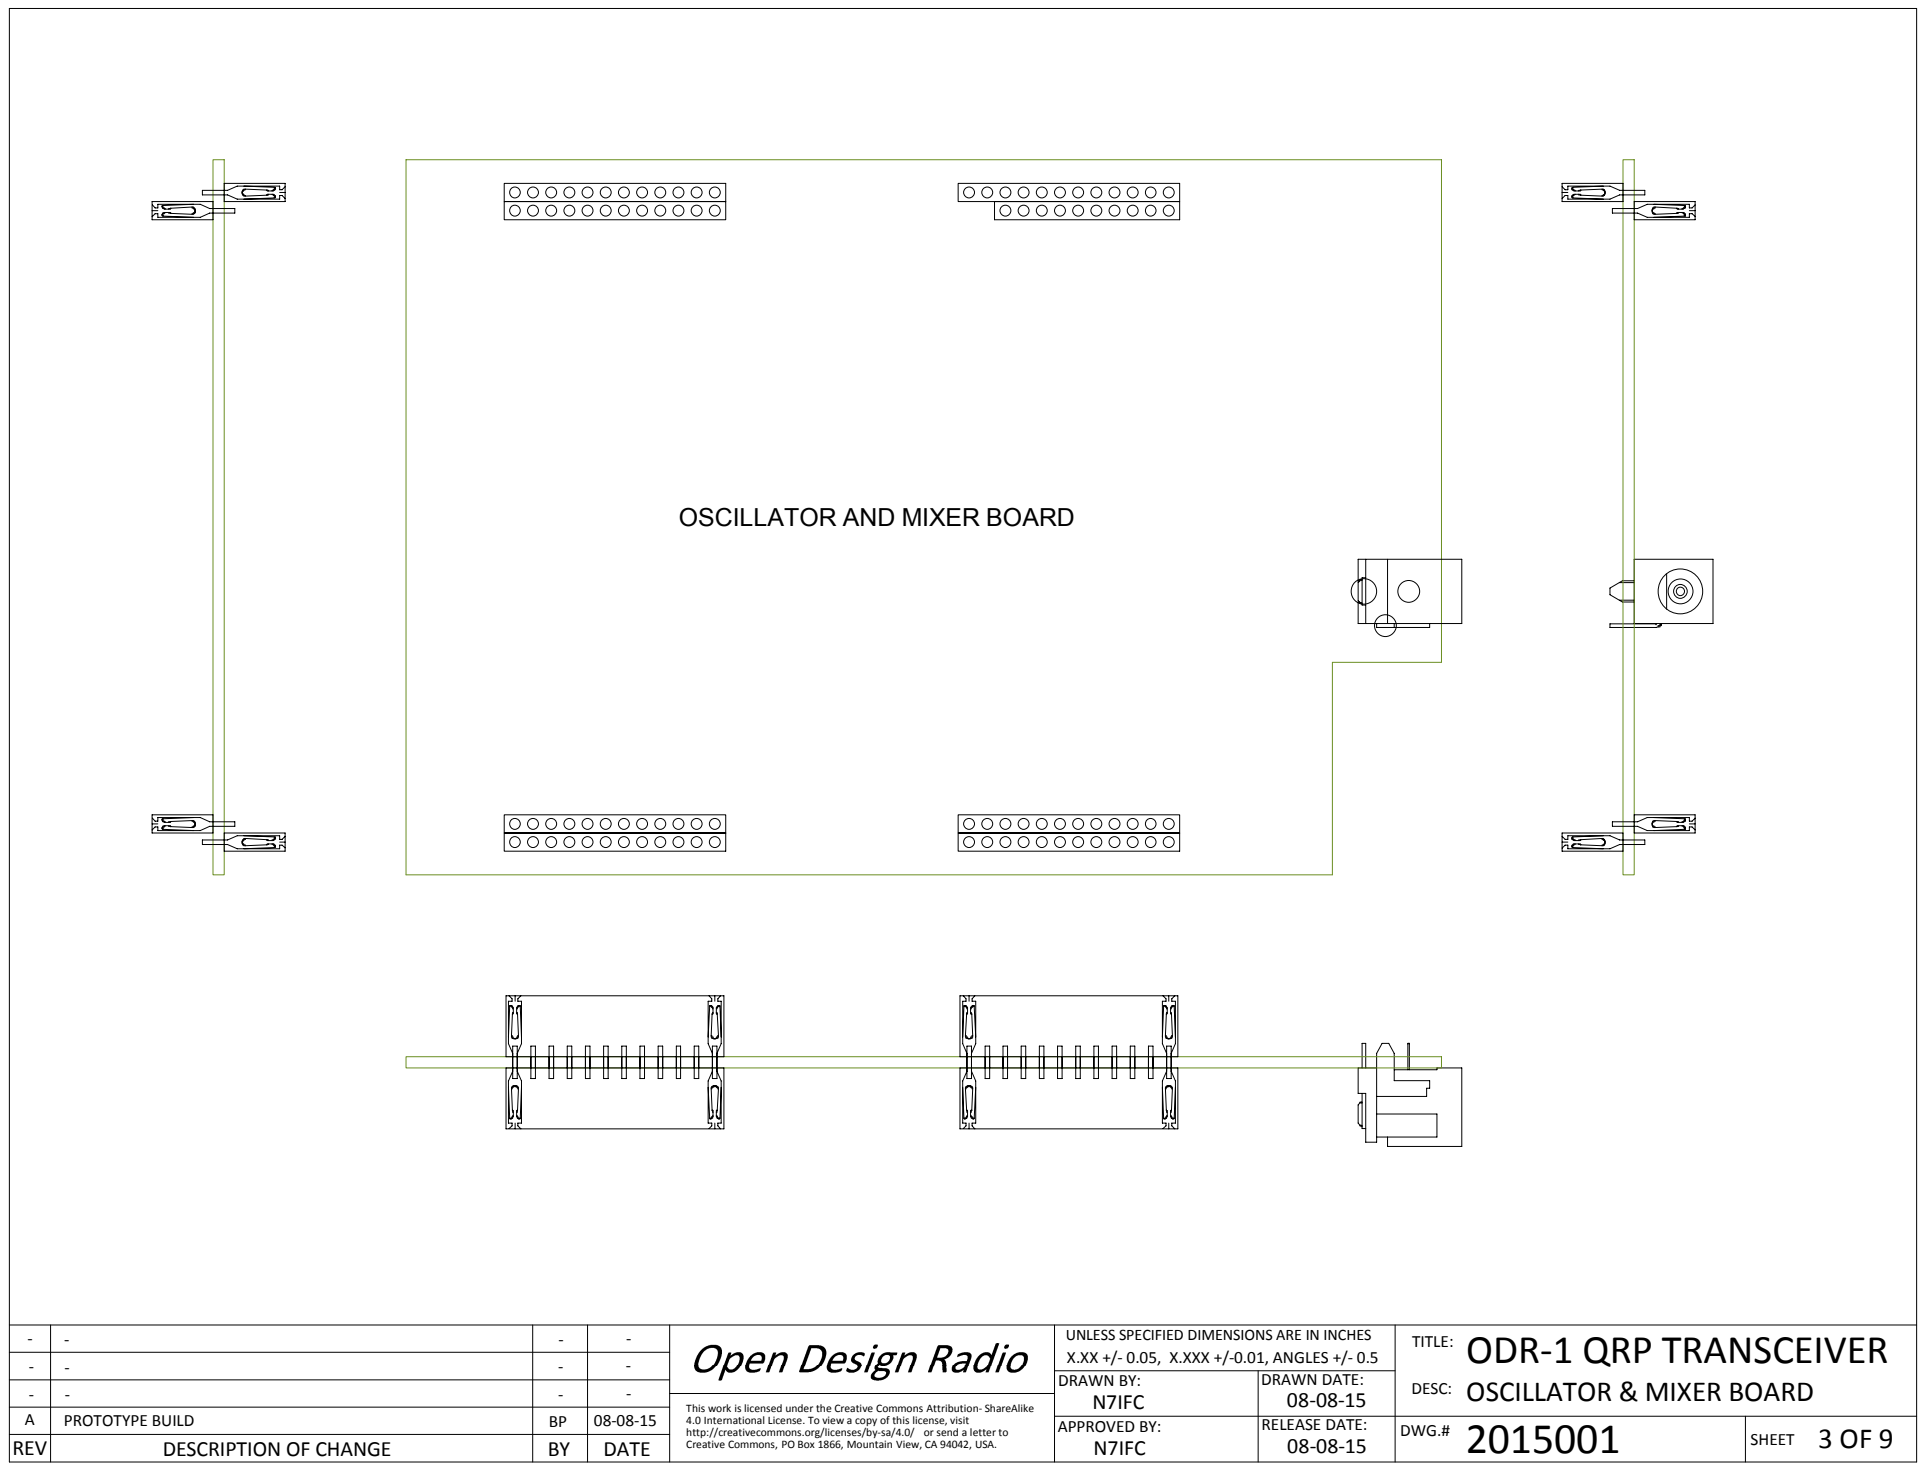
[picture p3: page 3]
TITLE:; PROTOTYPE BUILD; OSCILLATOR AND MIXER BOARD

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

ODR-1 QRP TRANSCEIVER
OSCILLATOR & MIXER BOARD

EE2

EE2

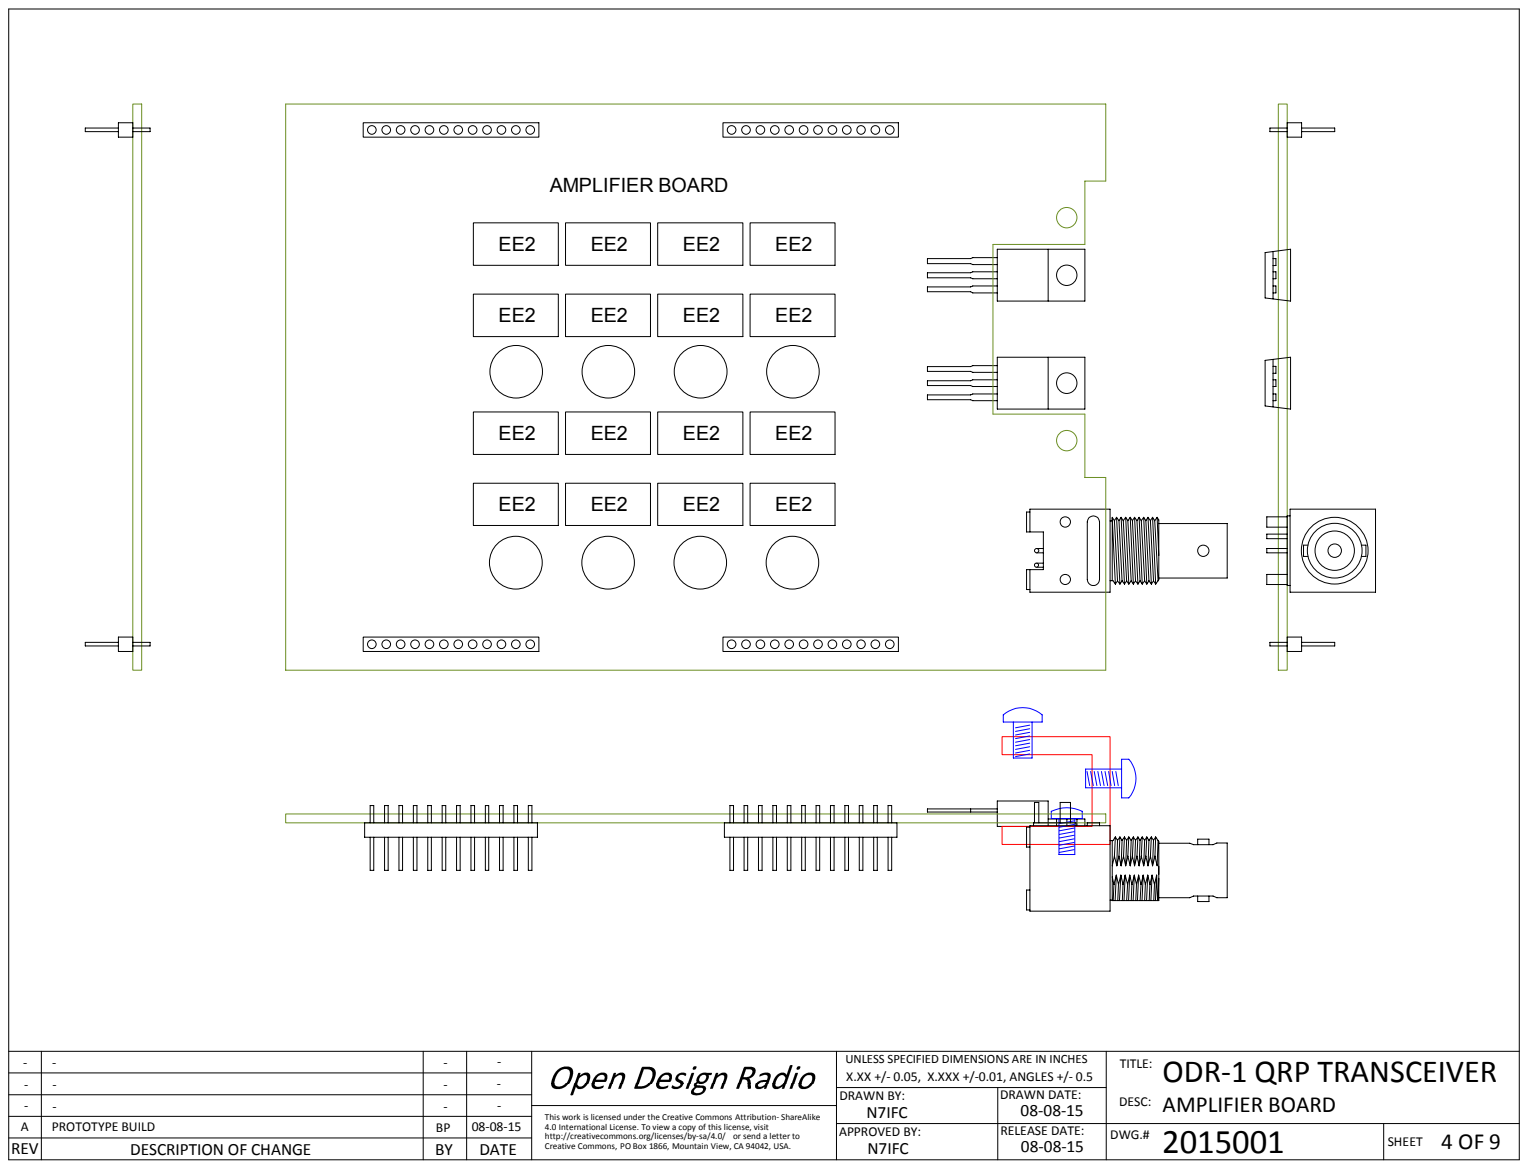
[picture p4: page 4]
TITLE:; PROTOTYPE BUILD; AMPLIFIER BOARD

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

ODR-1 QRP TRANSCEIVER
AMPLIFIER BOARD

# FRONT VIEW

# TIANMA

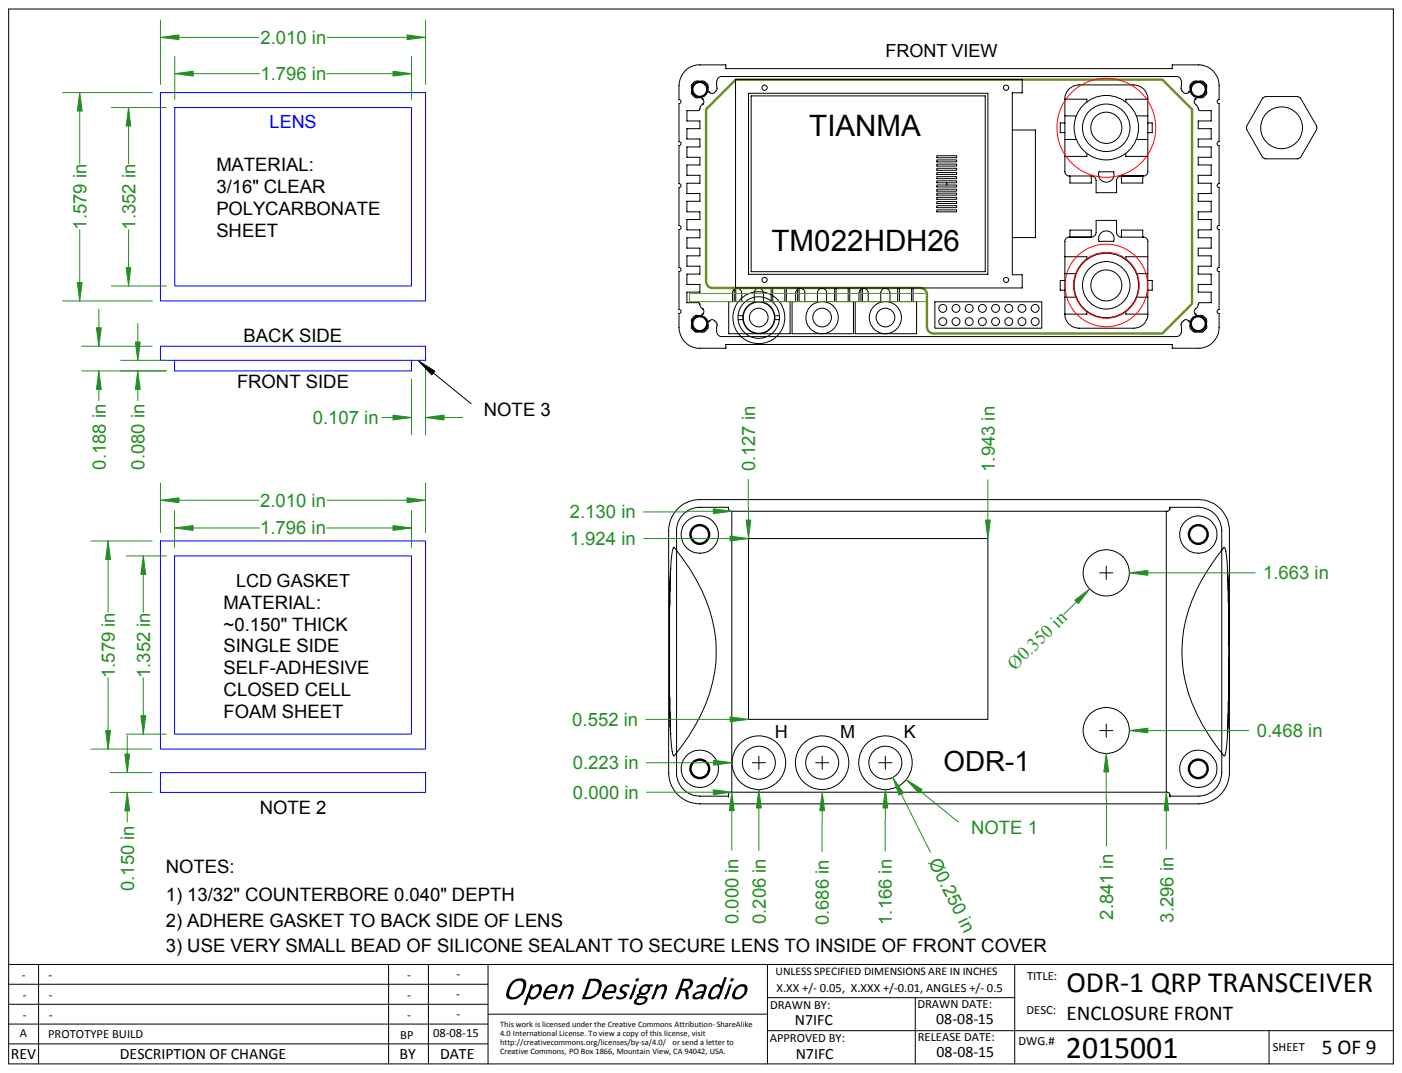
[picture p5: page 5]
TITLE:; PROTOTYPE BUILD; ODR-1; TM022HDH26; LENS; NOTE 1; MATERIAL: 3/16" CLEAR POLYCARBONATE SHEET; LCD GASKET MATERIAL: ~0.150" THICK SINGLE SIDE SELF-ADHESIVE CLOSED CELL FOAM SHEET; NOTE 2; BACK SIDE; FRONT SIDE; NOTE 3

NOTES:
1) 13/32" COUNTERBORE 0.040" DEPTH
2) ADHERE GASKET TO BACK SIDE OF LENS
3) USE VERY SMALL BEAD OF SILICONE SEALANT TO SECURE LENS TO INSIDE OF FRONT COVER

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

ODR-1 QRP TRANSCEIVER
ENCLOSURE FRONT

A | PROTOTYPE BUILD | BP | 08-08-15 - | - | - | - - | - | - | - - | - | - | - | BACK VIEW AUX | ETH USB DC ANT 0.000 in

# 1) 13/32" COUNTERBORE 0.040" DEPTH

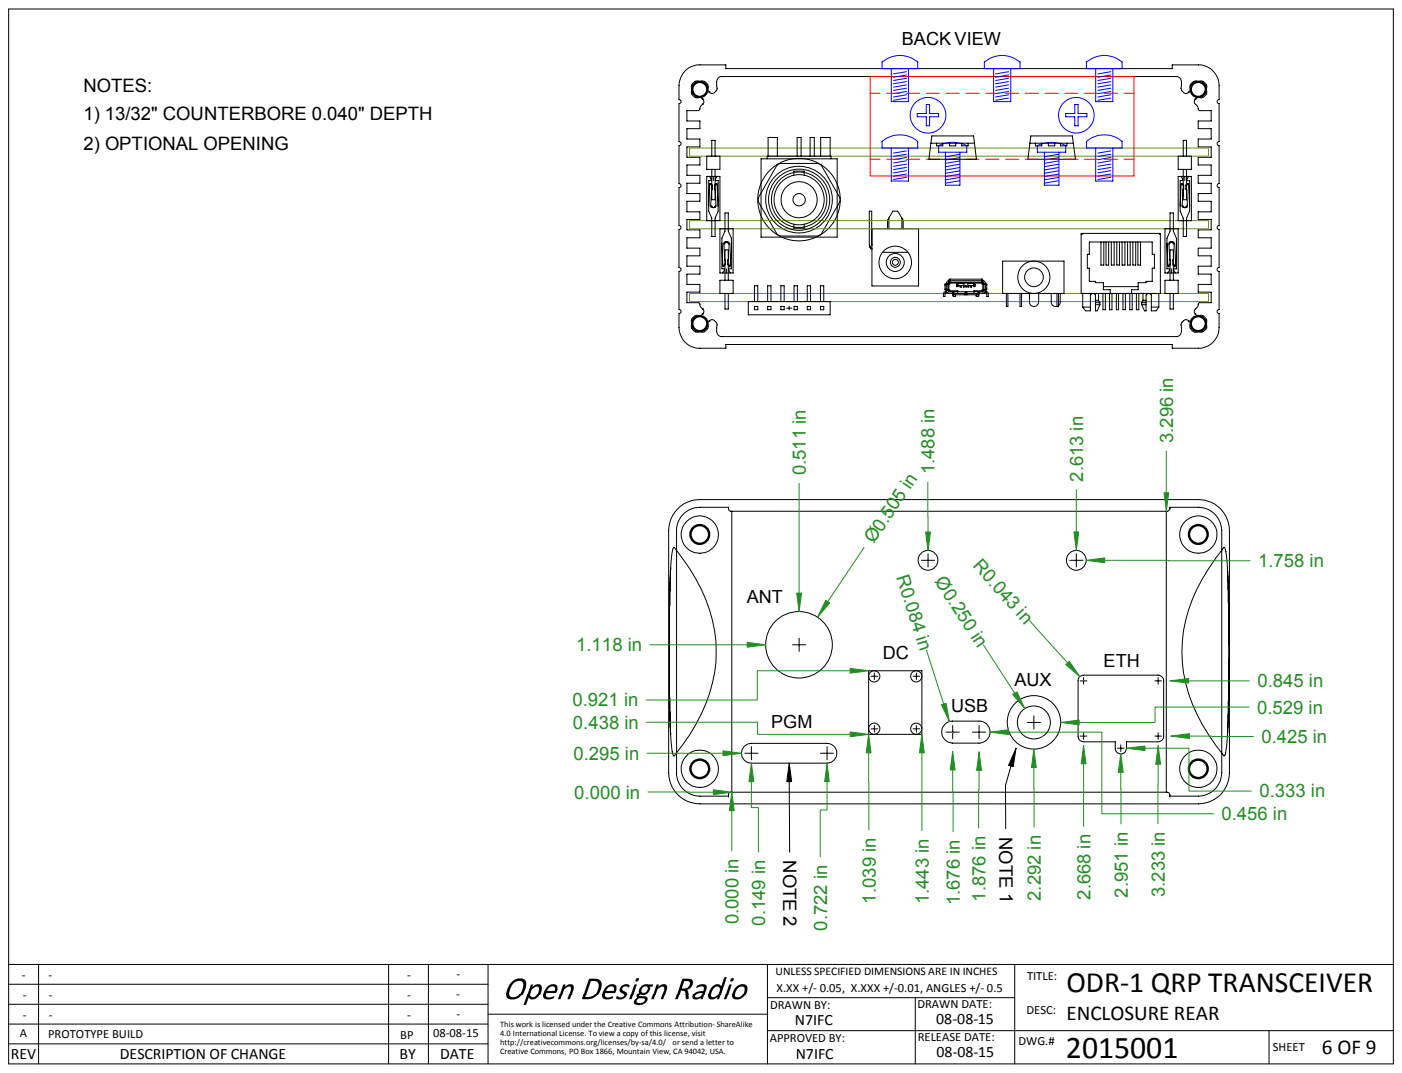
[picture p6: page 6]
TITLE:; PGM; NOTES:; 2) OPTIONAL OPENING

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

ODR-1 QRP TRANSCEIVER
ENCLOSURE REAR

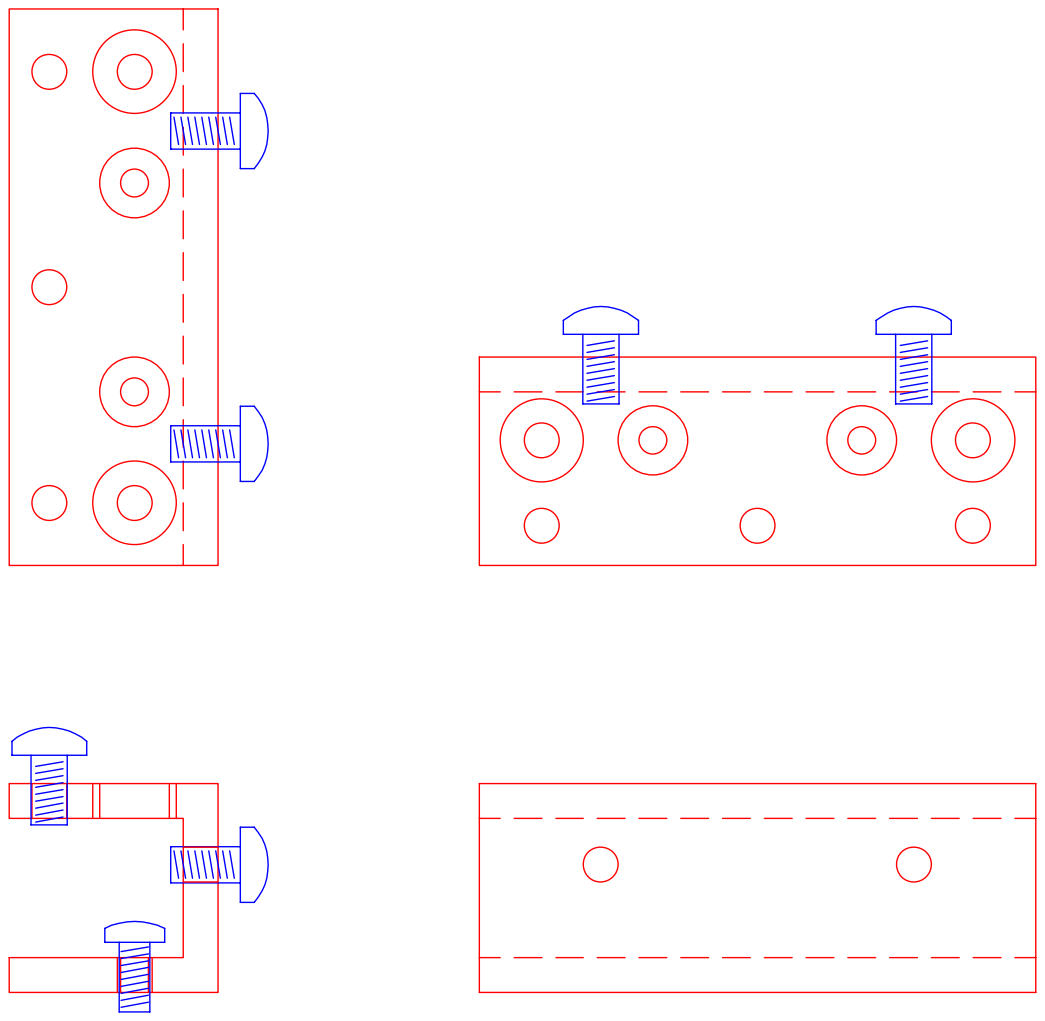
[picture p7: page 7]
TITLE:; PROTOTYPE BUILD

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

ODR-1 QRP TRANSCEIVER
INTERNAL HEATSINK

A | PROTOTYPE BUILD | BP | 08-08-15 - | - | - | - - | - | - | - - | - | - | - | HAMMOND 1457N1601 ENCLOSURE

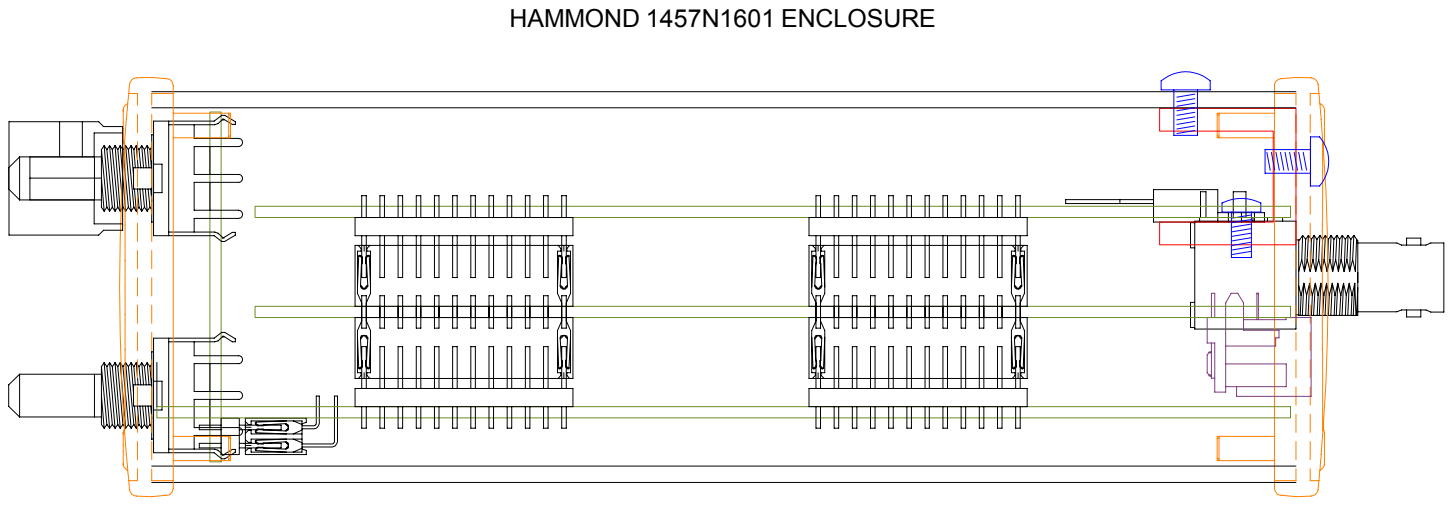
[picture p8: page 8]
TITLE:

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

ODR-1 QRP TRANSCEIVER
SIDE ENCLOSURE PROFILE

# HAMMOND 1457N1601 ENCLOSURE

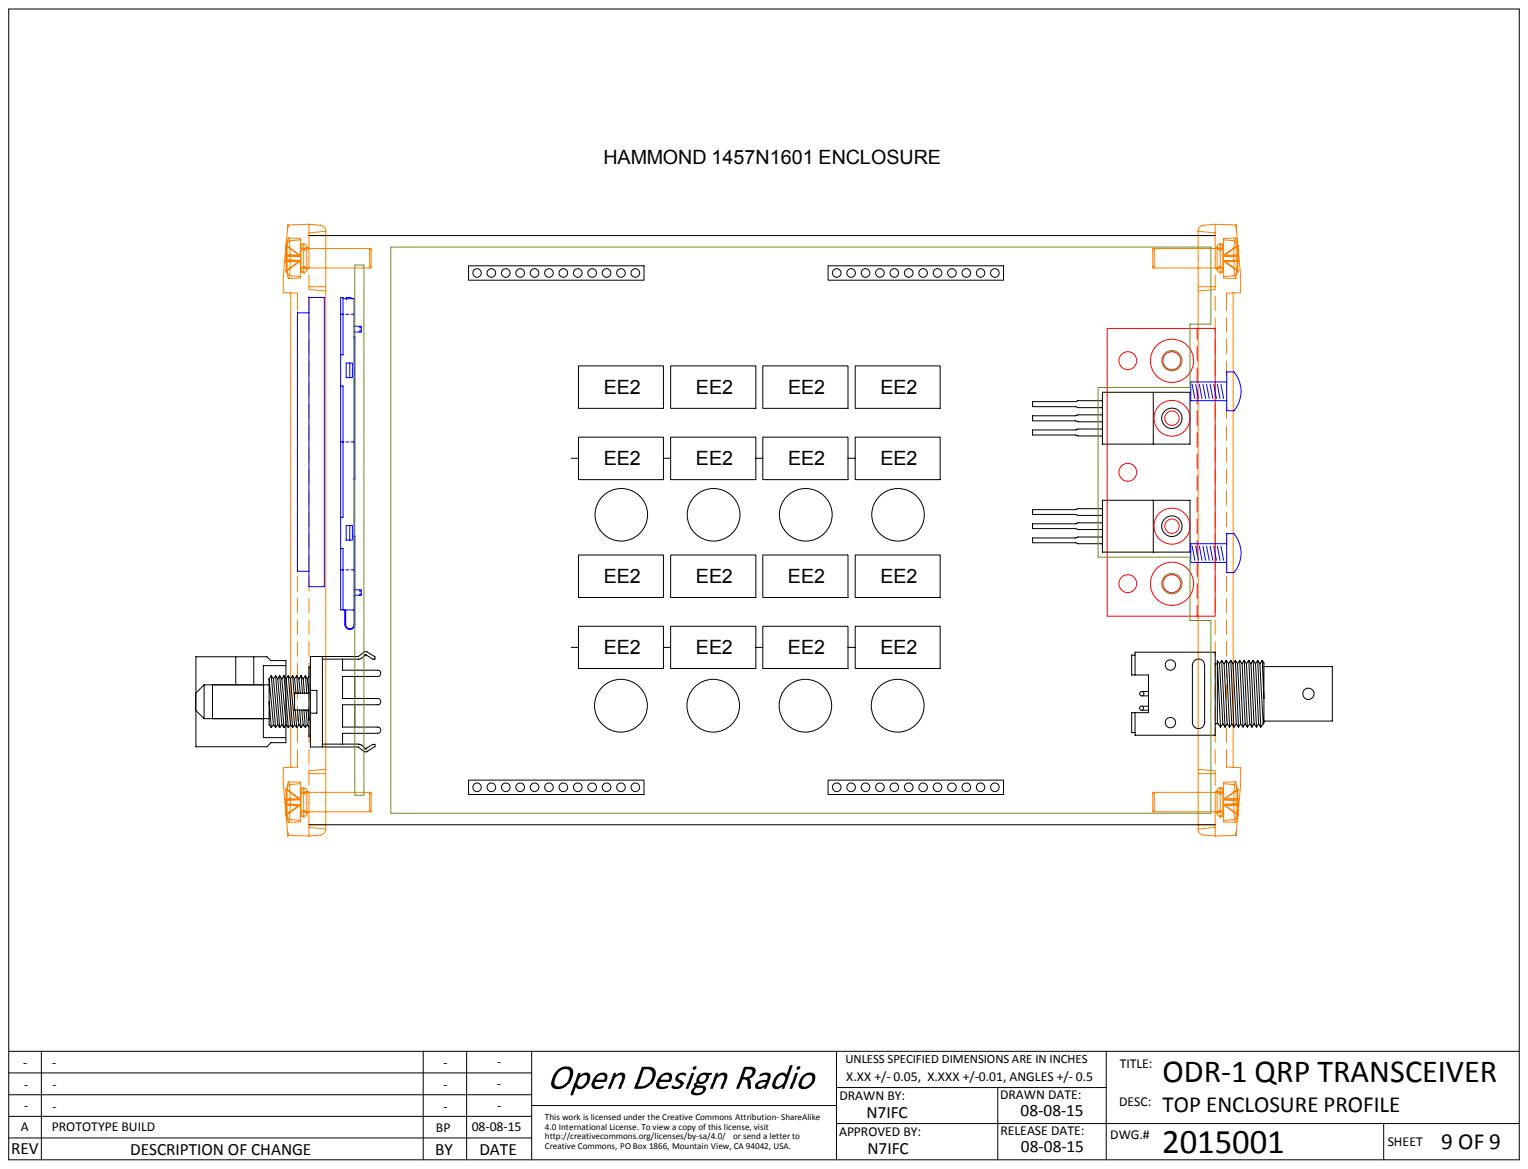
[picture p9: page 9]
TITLE:; PROTOTYPE BUILD

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

ODR-1 QRP TRANSCEIVER
TOP ENCLOSURE PROFILE

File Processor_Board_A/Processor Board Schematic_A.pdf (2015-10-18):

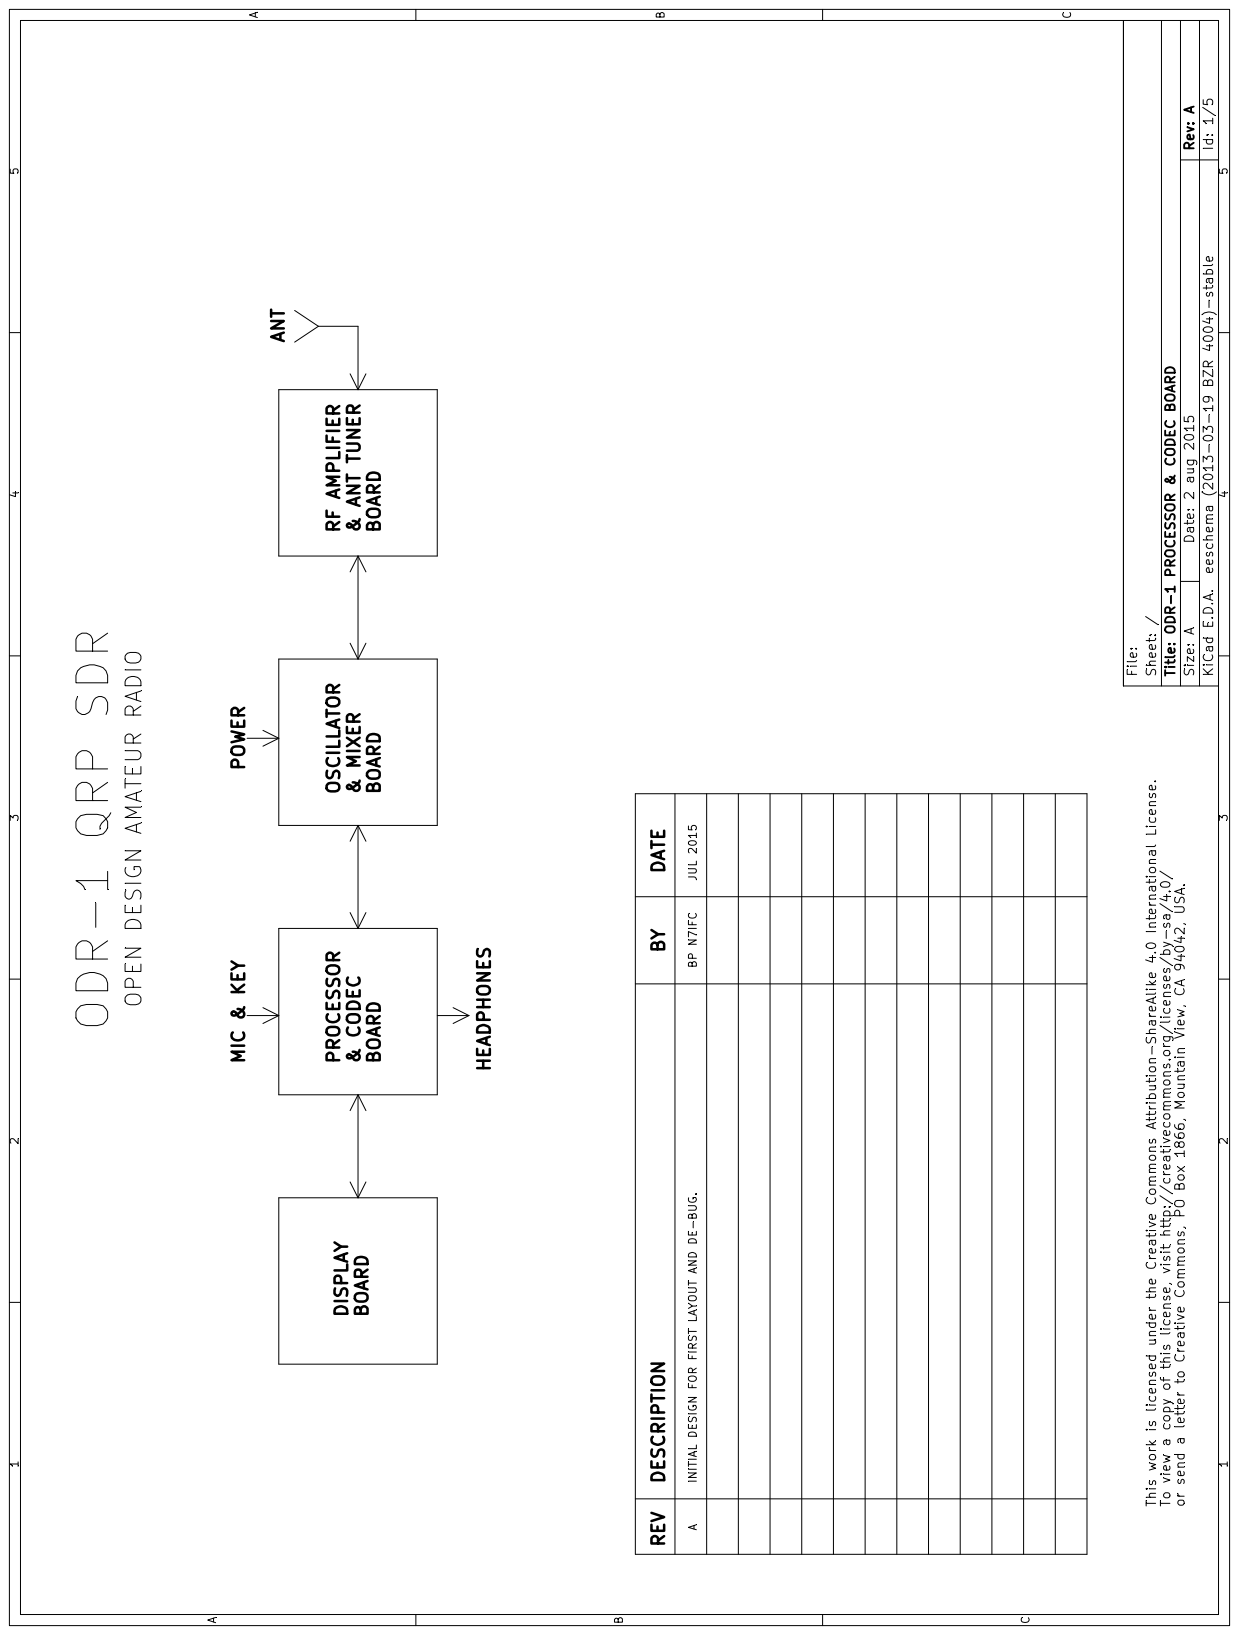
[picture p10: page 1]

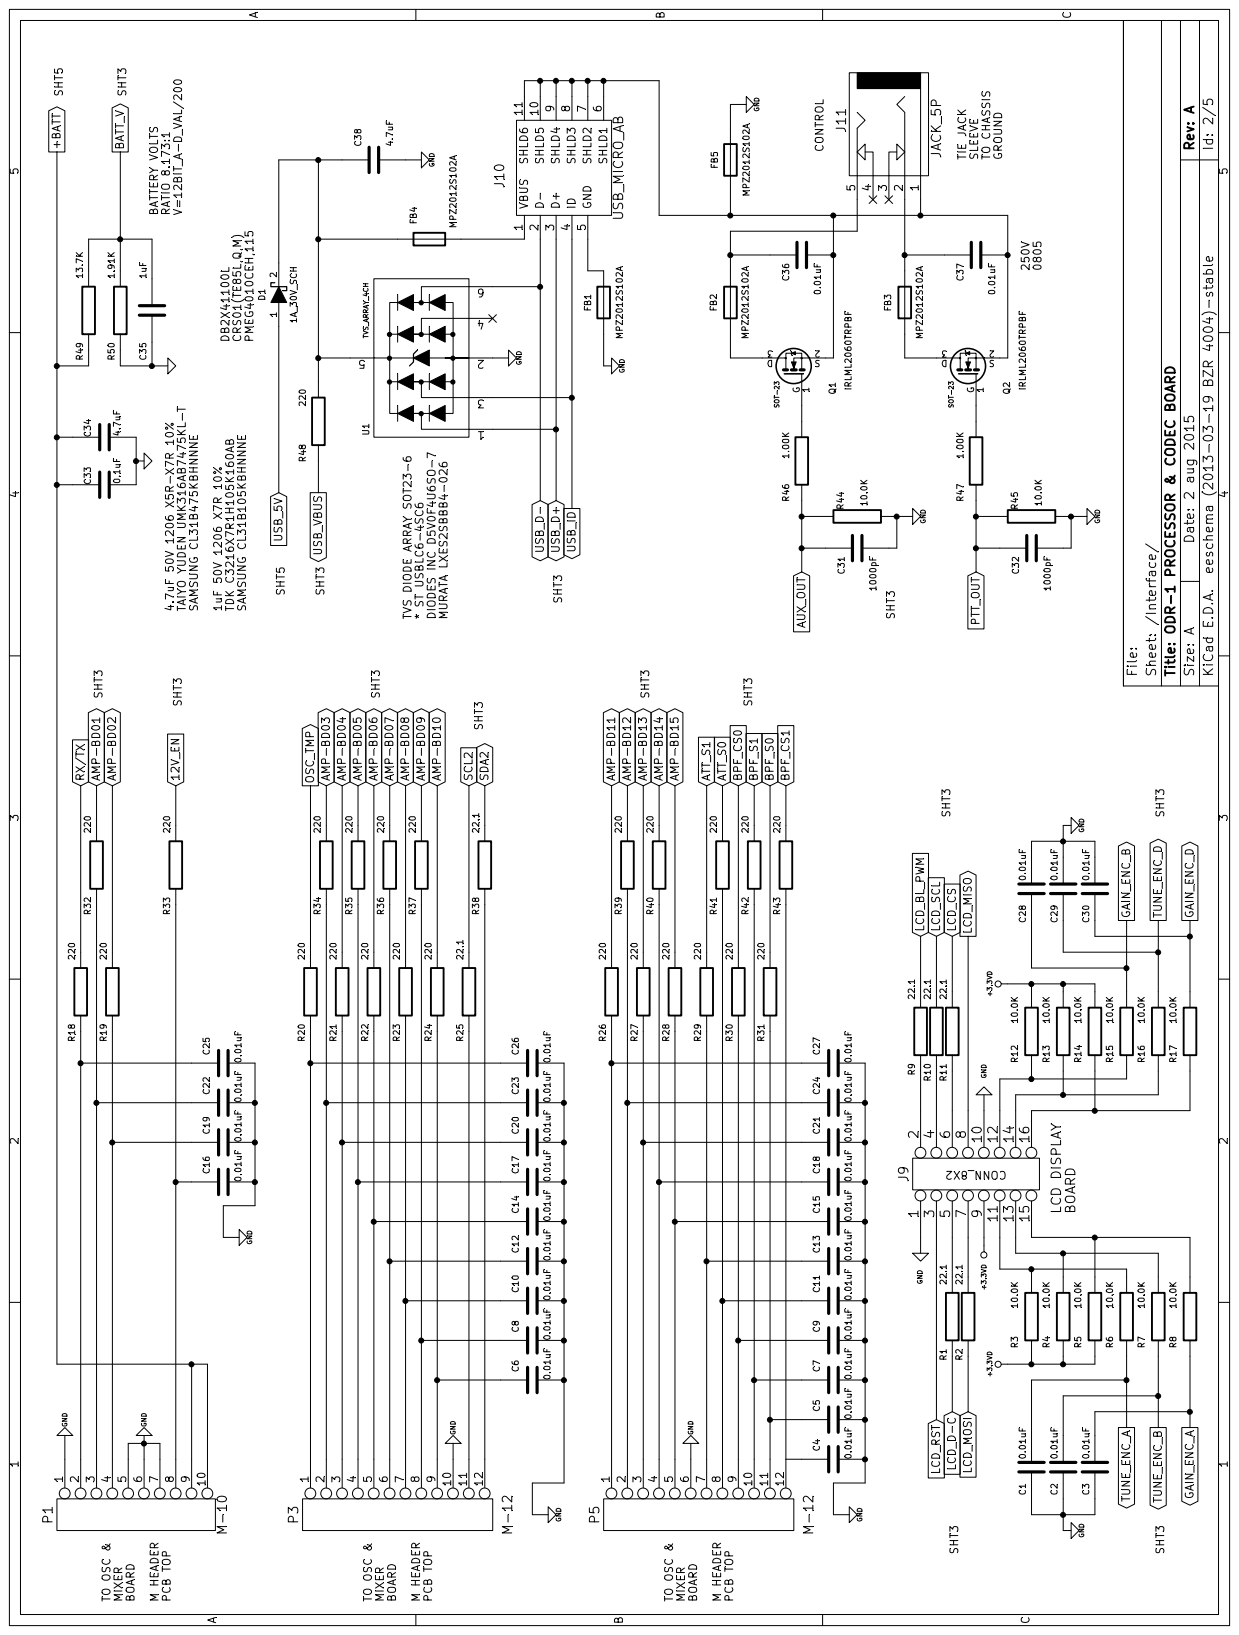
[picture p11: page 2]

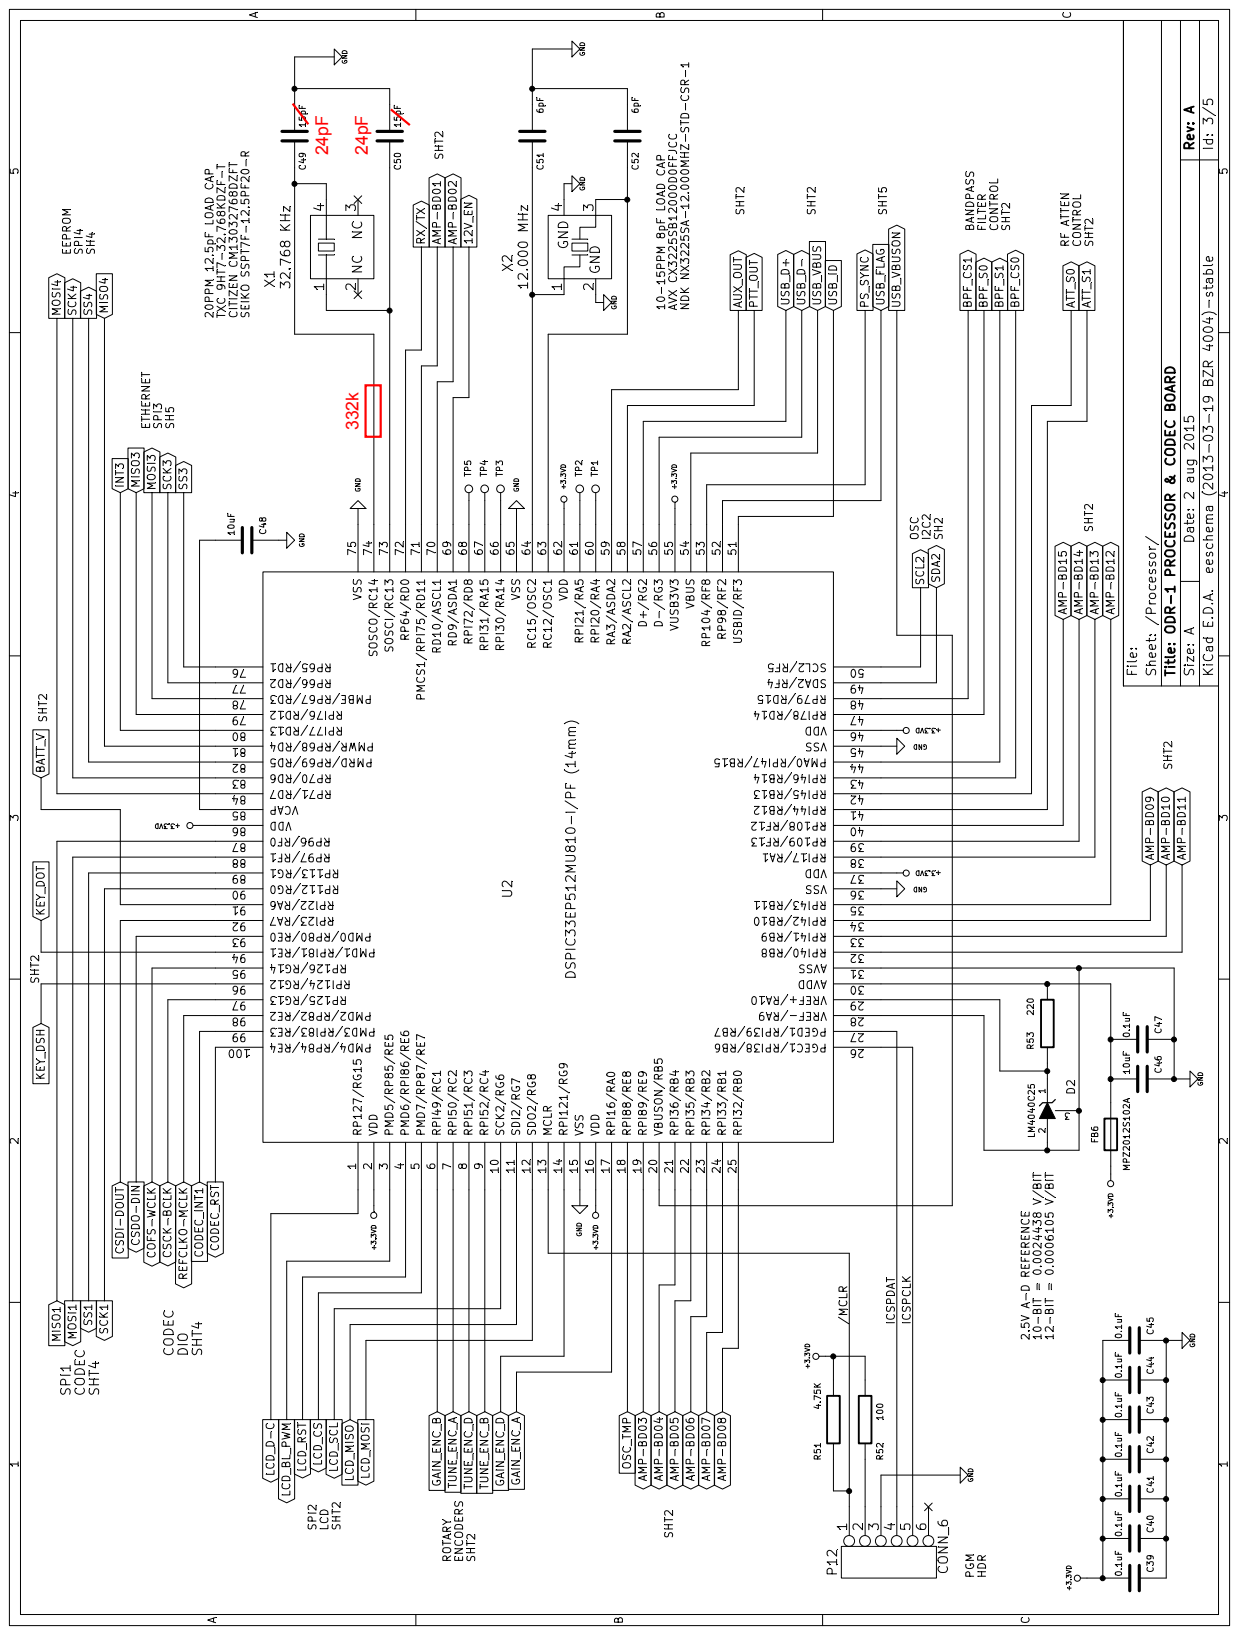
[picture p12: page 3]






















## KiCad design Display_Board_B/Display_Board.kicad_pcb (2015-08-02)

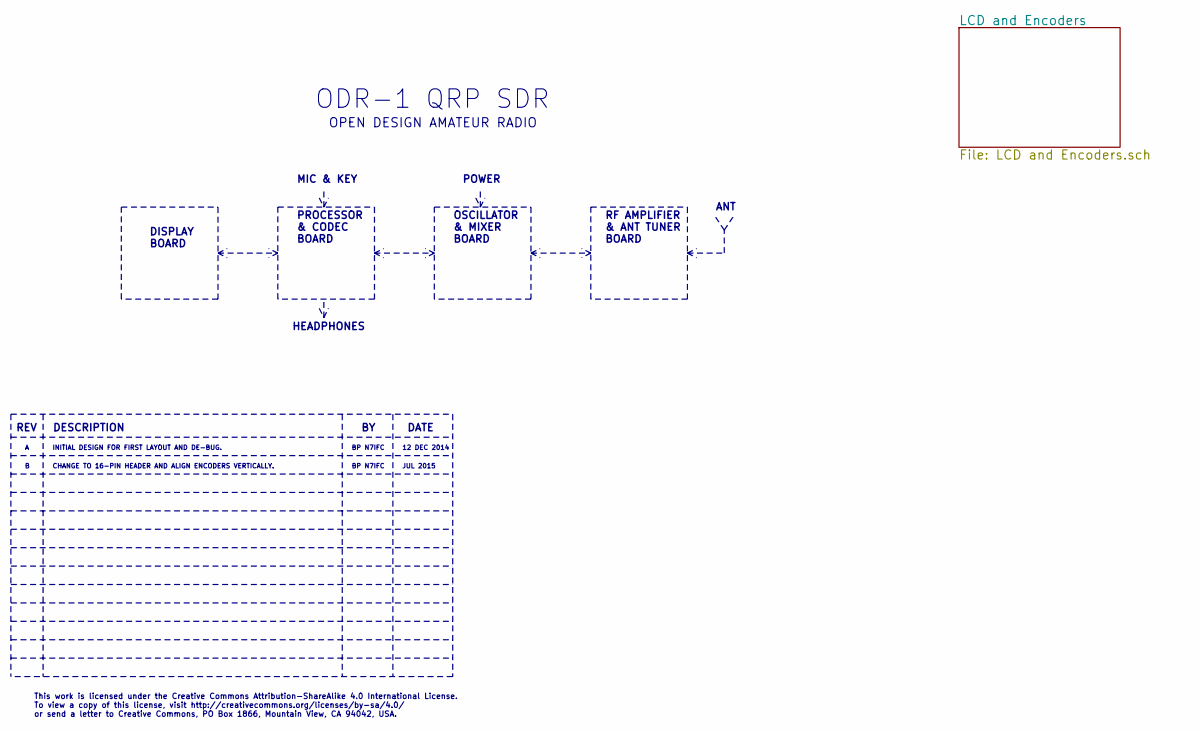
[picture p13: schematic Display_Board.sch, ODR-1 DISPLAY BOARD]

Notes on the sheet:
ODR-1 QRP SDR
REV
DESCRIPTION
DATE
INITIAL DESIGN FOR FIRST LAYOUT AND DE-BUG.
BP N7IFC
12 DEC 2014
DISPLAY BOARD
PROCESSOR & CODEC BOARD
OSCILLATOR & MIXER BOARD
RF AMPLIFIER & ANT TUNER BOARD
ANT
MIC & KEY
HEADPHONES
OPEN DESIGN AMATEUR RADIO
POWER
CHANGE TO 16-PIN HEADER AND ALIGN ENCODERS VERTICALLY.
JUL 2015
This work is licensed under the Creative Commons Attribution-ShareAlike 4.0 International License. To view a copy of this license, visit http://creativecommons.org/licenses/by-sa/4.0/ or send a letter to Creative Commons, PO Box 1866, Mountain View, CA 94042, USA.

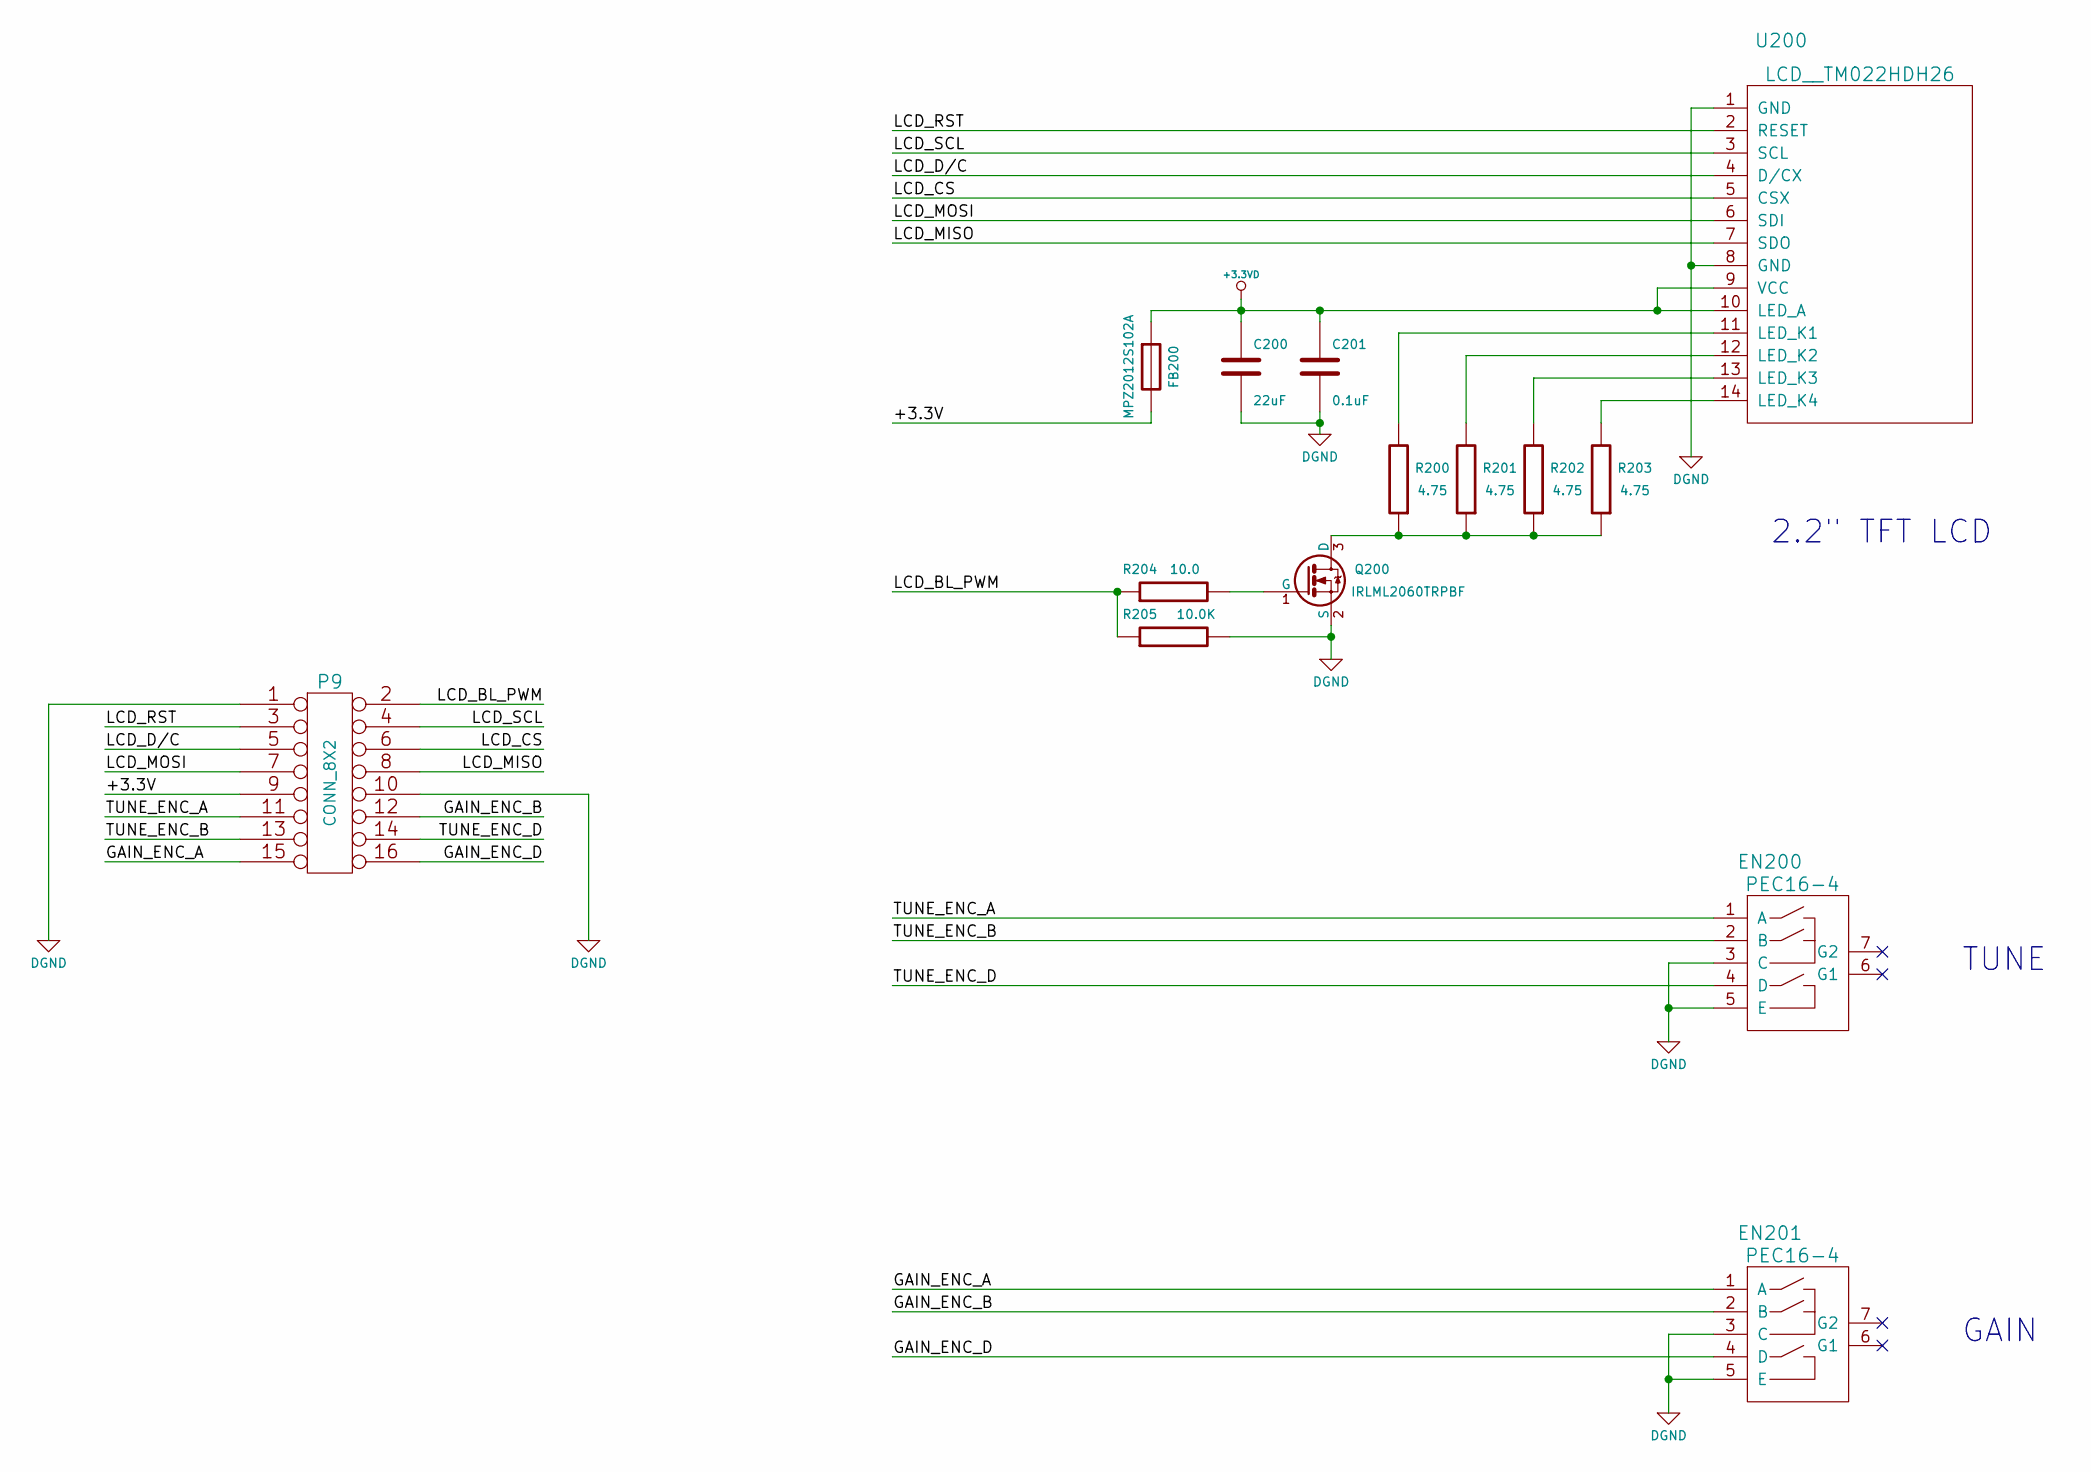
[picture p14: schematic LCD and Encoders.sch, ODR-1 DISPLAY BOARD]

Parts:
C200: 22uF; 0805
C201: 0.1uF
EN200, EN201: PEC16-4
FB200: MPZ2012S102A; 0805
P9: CONN_8X2
Q200: IRLML2060TRPBF; SOT-23
R200: 4.75
R201, R202, R203: 4.75; 0805
R204: 10.0; 0805
R205: 10.0K; 0805
U200: LCD__TM022HDH26

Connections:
+3.3VD: C200.1, C201.1, FB200.1, U200.9 (VCC), U200.10 (LED_A)
/LCD and Encoders/+3.3V: FB200.2, P9.9
/LCD and Encoders/GAIN_ENC_A: EN201.1 (A), P9.15
/LCD and Encoders/GAIN_ENC_B: EN201.2 (B), P9.12
/LCD and Encoders/GAIN_ENC_D: EN201.4 (D), P9.16
/LCD and Encoders/LCD_BL_PWM: P9.2, R204.1, R205.1
/LCD and Encoders/LCD_CS: P9.6, U200.5 (CSX)
/LCD and Encoders/LCD_D/C: P9.5, U200.4 (D/CX)
/LCD and Encoders/LCD_MISO: P9.8, U200.7 (SDO)
/LCD and Encoders/LCD_MOSI: P9.7, U200.6 (SDI)
/LCD and Encoders/LCD_RST: P9.3, U200.2 (RESET)
/LCD and Encoders/LCD_SCL: P9.4, U200.3 (SCL)
/LCD and Encoders/TUNE_ENC_A: EN200.1 (A), P9.11
/LCD and Encoders/TUNE_ENC_B: EN200.2 (B), P9.13
/LCD and Encoders/TUNE_ENC_D: EN200.4 (D), P9.14
DGND: C200.2, C201.2, EN200.3 (C), EN200.5 (E), EN201.3 (C), EN201.5 (E), P9.1, P9.10, Q200.2 (S), R205.2, U200.1 (GND), U200.8 (GND)
unnamed: Q200.1 (G), R204.2
unnamed: Q200.3 (D), R200.1, R201.1, R202.1, R203.1
unnamed: R202.2, U200.13 (LED_K3)
unnamed: R200.2, U200.11 (LED_K1)
unnamed: R201.2, U200.12 (LED_K2)
unnamed: R203.2, U200.14 (LED_K4)

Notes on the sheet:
TUNE
GAIN
2.2" TFT LCD

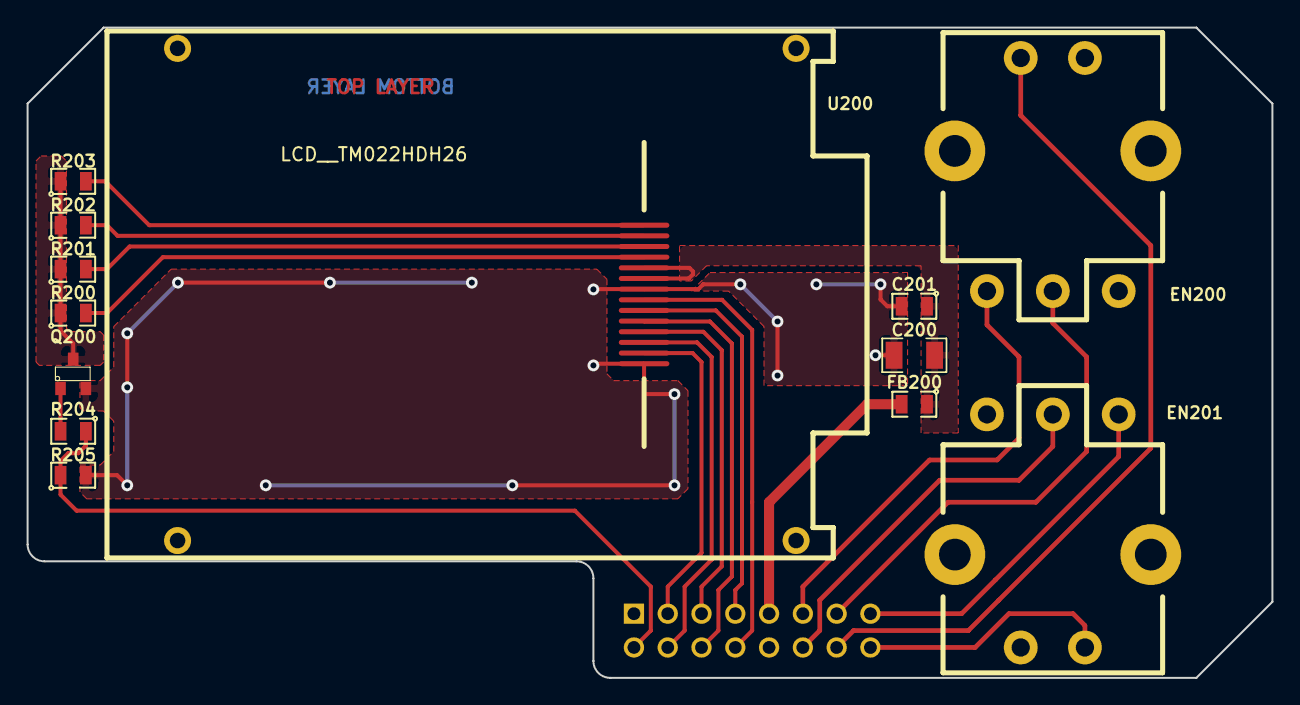
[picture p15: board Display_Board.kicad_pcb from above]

Board: 2 copper layers, 93.6 x 48.9 mm, 14 parts (1 on the bottom side), 22 nets.

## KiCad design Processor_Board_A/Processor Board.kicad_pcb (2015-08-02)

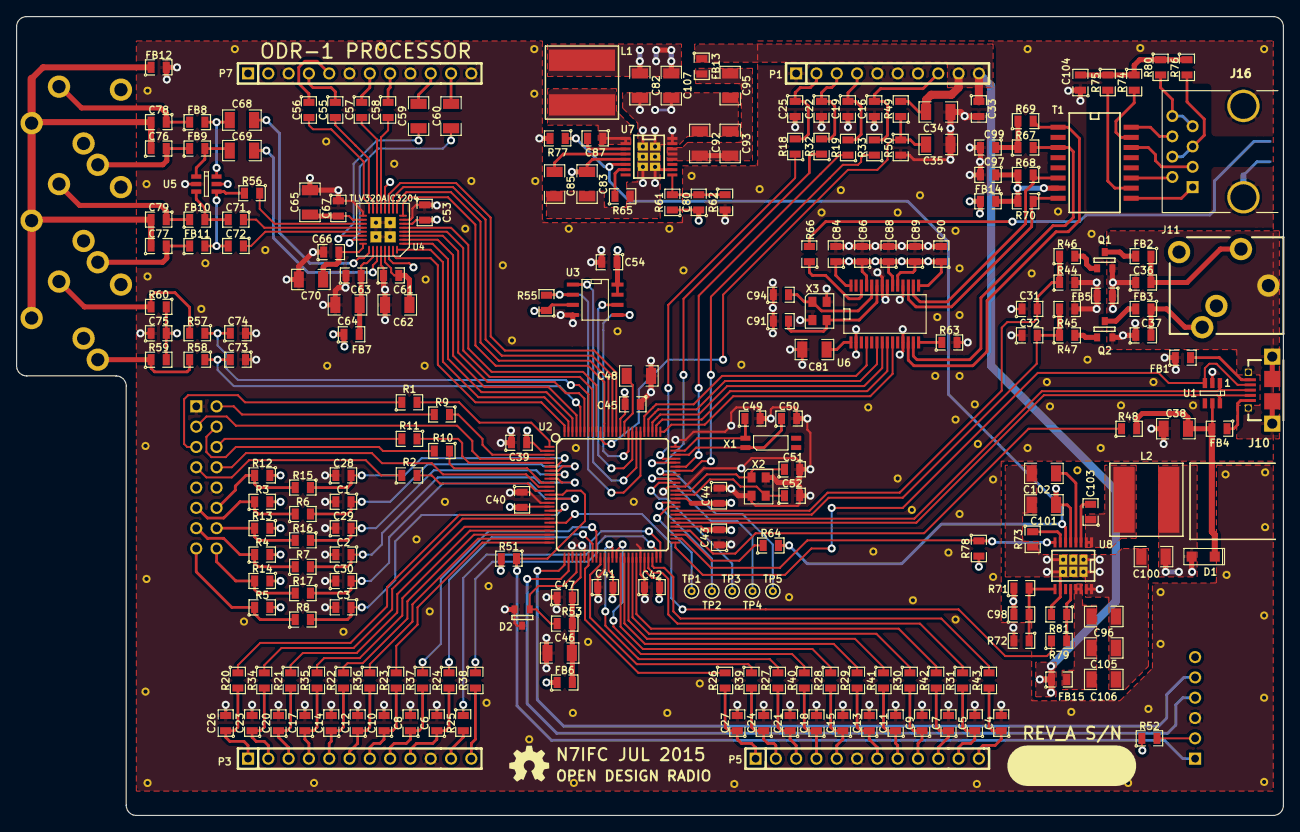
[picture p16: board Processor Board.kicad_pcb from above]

Board: 4 copper layers, 158.5 x 99.9 mm, 338 parts (0 on the bottom side), 205 nets.

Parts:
C1, C2, C3, C4, C5, C6, C7, C8, C9, C10, C11, C12, C13, C14, C15, C16, C17, C18, C19, C20, C21, C22, C23, C24, C25, C26, C27, C28, C29, C30, C36, C37, C73, C74, C75: 0.01uF; SM0805-1
C31, C32, C76, C77, C78, C79, C104: 1000pF; SM0805-1
C33, C39, C40, C41, C42, C43, C44, C45, C47, C53, C54, C61, C63, C66, C67, C71, C72, C84, C86, C88, C89, C90, C97, C99: 0.1uF; SM0805-1
C34, C38, C81, C83, C93, C95, C101, C105, C106: 4.7uF; SM1206-1
C35, C59, C60, C92, C96: 1uF; SM1206-1
C46, C48, C62, C65: 10uF; SM1206-1
C49, C50, C80, C98: 15pF; SM0805-1
C51, C52, C91, C94: 6pF; SM0805-1
C55, C56, C57, C58: 0.22uF; SM0805-1
C64, C70, C100: 22uF; SM1206-1
C68, C69, C82, C107: 47uF; SM1206-1
C85, C102: 2.2uF; SM1206-1
C87, C103: 0.47uF; SM0805-1
D1: 1A_30V_SCH; SOD123F
D2: LM4040C25; SOT23-1
D3: GRN; SM_LED_RA
FB1, FB2, FB3, FB4, FB5, FB6, FB7, FB12, FB13, FB15: MPZ2012S102A; SM0805-1
FB8, FB9, FB10, FB11, FB14: MMZ2012R102A; SM0805-1
J9: CONN_8X2; HDR_8x2_RA
J10: USB_MICRO_AB
J11, J13, J14, J15: JACK_5P; AUDIO-5
J16: RJ45_LP_UNS; RJ45-8LP
L1: 10uH; SM2233
L2: 22uH; SM2233
P1: M-10; SIL-10-1
P3, P5, P7: M-12; SIL-12-1
P12: CONN_6; SIL-6_RA
Q1, Q2: IRLML2060TRPBF; SOT23-1
R1, R2, R9, R10, R11, R25, R38, R64: 22.1; SM0805-1
R3, R4, R5, R6, R7, R8, R12, R13, R14, R15, R16, R17, R44, R45, R55, R57, R58, R59, R60, R78: 10.0K; SM0805-1
R18, R19, R20, R21, R22, R23, R24, R26, R27, R28, R29, R30, R31, R32, R33, R34, R35, R36, R37, R39, R40, R41, R42, R43, R48, R53: 220; SM0805-1
R46, R47, R77, R79: 1.00K; SM0805-1
R49: 13.7K; SM0805-1
R50: 1.91K; SM0805-1
R51: 4.75K; SM0805-1
R52: 100; SM0805-1
R56: 2.70K; SM0805-1
R61, R71: 1M; SM0805-1
R62: 432K; SM0805-1
R63: 2.32K; SM0805-1
R65, R73: 40.2K; SM0805-1
R66: 270; SM0805-1
R67, R68, R69, R70: 49.9; SM0805-1
R72: 249K; SM0805-1
R74, R75, R76, R80: 75.0; SM0805-1
R81: 100K; SM0805-1
T1: TRANSFO_ETHER; XFMR_ETH16
TP1, TP2, TP3, TP4, TP5: TP_1; TP_TH
U1, U5: TVS_ARRAY_4CH; SOT23-6L
U2: DSPIC33EP512MU810-I/PF (14mm); TQFP_100_14MM
U3: M95256; SO8N-1
U4: TLV320AIC3204; VQFN32
U6: ENC28J60-I/SS; SSOP28-1
U7: LM43601; PWRPAD16
U8: LM43600; PWRPAD16
X1: 32.768 KHz; CRYSTAL_4L
X2: 12.000 MHz; CRYSTAL_4
X3: 25MHz; CRYSTAL_4
x: x; ViaGND40
x#2, x#3, x#4, x#5, x#6, x#7, x#8, x#9, x#10, x#11, x#12, x#13, x#14, x#15, x#16, x#17, x#18, x#19, x#20, x#21, x#22, x#23, x#24, x#25, x#26, x#27, x#28, x#29, x#30, x#31, x#32, x#33, x#34, x#35, x#36, x#37, x#38, x#39, x#40, x#41, x#42, x#43, x#44, x#45, x#46, x#47, x#48, x#49, x#50, x#51, x#52, x#53, x#54, x#55, x#56, x#57, x#58, x#59, x#60, x#61, x#62, x#63, x#64, x#65, x#66, x#67, x#68, x#69, x#70, x#71, x#72, x#73, x#74, x#75, x#76, x#77, x#78, x#79, x#80, x#81, x#82, x#83, x#84, x#85, x#86, x#87, x#88, x#89, x#90, x#91, x#92, x#93, x#94, x#95, x#96, x#97, x#98, x#99, x#100: x; ViaGND40

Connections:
12V_EN: R33.1, U2.69
+3.3VD: C39.2, C40.2, C41.2, C42.2, C43.2, C44.2, C45.2, C53.2, C54.1, C75.2, C80.1, C82.1, C83.1, C84.1, C86.1, C88.1, C89.1, C90.1, C107.1, FB6.1, FB7.1, FB14.2, J9.9, L1.1, R3.2, R4.2, R5.2, R12.1, R13.1, R14.1, R51.2, R52.1, R55.1, R59.2, R60.1, R61.1, R78.2, U2.2, U2.16, U2.37, U2.46, U2.55, U2.62, U2.86, U3.3, U3.7, U3.8, U4.6, U4.12, U4.30, U5.5, U6.15, U6.19, U6.20, U6.25, U6.28, U7.5
+BATT: C33.1, C34.1, FB13.1, FB15.1, P1.9, P1.10, R49.2
/Codec/RX_I+: C55.1, P7.4
/Codec/RX_I-: C56.1, P7.5
/Codec/RX_Q+: C57.1, P7.7
/Codec/RX_Q-: C58.1, P7.8
/Codec/TX_I: C59.1, P7.10
/Codec/TX_Q: C60.1, P7.11
/Processor//MCLR: P12.1, R51.1, U2.13
/Processor/ICSPCLK: P12.5, U2.26
/Processor/ICSPDAT: P12.4, U2.27
AMP-BD01: R32.1, U2.71
AMP-BD02: R19.1, U2.70
AMP-BD03: R34.1, U2.19
AMP-BD04: R21.1, U2.21
AMP-BD05: R35.1, U2.22
AMP-BD06: R22.1, U2.23
AMP-BD07: R36.1, U2.24
AMP-BD08: R23.1, U2.25
AMP-BD09: R37.1, U2.34
AMP-BD10: R24.1, U2.33
AMP-BD11: R26.1, U2.32
AMP-BD12: R39.1, U2.35
AMP-BD13: R27.1, U2.38
AMP-BD14: R40.1, U2.39
AMP-BD15: R28.1, U2.40
ATT_S0: R41.1, U2.42
ATT_S1: R29.1, U2.41
AUX_OUT: C31.2, R44.1, R46.1, U2.59
BATT_V: C35.1, R49.1, R50.1, U2.91
BPF_CS0: R30.1, U2.43
BPF_CS1: R43.1, U2.48
BPF_S0: R31.1, U2.47
BPF_S1: R42.1, U2.44
CODEC_INT1: U2.99, U4.32
CODEC_RST: U2.100, U4.31
COFS-WCLK: U2.95, U4.3
CSCK-BCLK: U2.97, U4.2
CSDI-DOUT: U2.92, U4.5
CSDO-DIN: U2.93, U4.4
GAIN_ENC_A: C3.1, R8.2, U2.17
GAIN_ENC_B: C28.2, R15.1, U2.6
GAIN_ENC_D: C30.2, R17.1, U2.14
GND: C1.2, C2.2, C3.2, C4.2, C5.2, C6.2, C7.2, C8.2, C9.2, C10.2, C11.2, C12.2, C13.2, C14.2, C15.2, C16.2, C17.2, C18.2, C19.2, C20.2, C21.2, C22.2, C23.2, C24.2, C25.2, C26.2, C27.2, C28.1, C29.1, C30.1, C31.1, C32.1, C33.2, C34.2, C35.2, C38.1, C39.1, C40.1, C41.1, C42.1, C43.1, C44.1, C45.1, C46.1, C47.1, C48.1, C49.2, C50.2, C51.2, C52.2, C53.1, C54.2, C61.1, C62.1, C63.1, C64.1, C65.1, C66.1, C67.1, C70.1, C73.1, C74.2, C75.1, C81.2, C82.2, C83.2, C84.2, C85.2, C86.2, C88.2, C89.2, C90.2, C91.1, C92.2, C93.2, C94.1, C95.2, C96.2, C97.2, C99.2, C100.2, C101.2, C102.2, C104.1, C105.2, C106.2, C107.2, D2.2, D2.3, D3.2, FB1.1, FB5.2, FB12.2, J9.1, J9.10, J16.9, J16.10, P1.1, P1.5, P1.6, P1.7, P3.10, P5.6, P7.3, P7.6, P7.9, P7.12, P12.3, R44.2, R45.2, R50.2, R62.2, R63.2, R65.2, R72.2, R73.2, R77.2, R81.2, U1.2, U2.15, U2.28, U2.31, U2.36, U2.45, U2.65, U2.75, U3.4, U4.7, U4.17, U4.28, U4.33, U5.2, U6.2, U6.11, U6.18, U6.21, U6.22, U7.10, U7.15, U7.16, U7.17, U8.10, U8.15, U8.16, U8.17, X2.2, X2.4, X3.2, X3.4, x.1, x#2.1, x#3.1, x#4.1, x#5.1, x#6.1, x#7.1, x#8.1, x#9.1, x#10.1, x#11.1, x#12.1, x#13.1, x#14.1, x#15.1, x#16.1, x#17.1, x#18.1, x#19.1, x#20.1, x#21.1, x#22.1, x#23.1, x#24.1, x#25.1, x#26.1, x#27.1, x#28.1, x#29.1, x#30.1, x#31.1, x#32.1, x#33.1, x#34.1, x#35.1, x#36.1, x#37.1, x#38.1, x#39.1, x#40.1, x#41.1, x#42.1, x#43.1, x#44.1, x#45.1, x#46.1, x#47.1, x#48.1, x#49.1, x#50.1, x#51.1, x#52.1, x#53.1, x#54.1, x#55.1, x#56.1, x#57.1, x#58.1, x#59.1, x#60.1, x#61.1, x#62.1, x#63.1, x#64.1, x#65.1, x#66.1, x#67.1, x#68.1, x#69.1, x#70.1, x#71.1, x#72.1, x#73.1, x#74.1, x#75.1, x#76.1, x#77.1, x#78.1, x#79.1, x#80.1, x#81.1, x#82.1, x#83.1, x#84.1, x#85.1, x#86.1, x#87.1, x#88.1, x#89.1, x#90.1, x#91.1, x#92.1, x#93.1, x#94.1, x#95.1, x#96.1, x#97.1, x#98.1, x#99.1, x#100.1
INT3: U2.80, U6.4
KEY_DOT: C74.1, R57.1, U2.94
KEY_DSH: C73.2, R58.1, U2.96
LCD_BL_PWM: R9.1, U2.3
LCD_CS: R11.1, U2.5
LCD_D-C: R1.2, U2.1
LCD_MISO: J9.8, U2.11
LCD_MOSI: R2.2, U2.12
LCD_RST: J9.3, U2.4
LCD_SCL: R10.1, U2.10
MISO1: U2.87, U4.11
MISO3: U2.79, U6.6
MISO4: R55.2, U2.81, U3.2
MOSI1: U2.88, U4.10
MOSI3: U2.78, U6.7
MOSI4: U2.84, U3.5
unnamed: C6.1, P3.9, R24.2
unnamed: C8.1, P3.8, R37.2
unnamed: C10.1, P3.7, R23.2
unnamed: C12.1, P3.6, R36.2
unnamed: C14.1, P3.5, R22.2
unnamed: C17.1, P3.4, R35.2
unnamed: C20.1, P3.3, R21.2
unnamed: P3.11, R25.2
unnamed: P3.12, R38.2
unnamed: C26.1, P3.1, R20.2
unnamed: C23.1, P3.2, R34.2
unnamed: J9.4, R10.2
unnamed: J9.6, R11.2
unnamed: C5.1, P5.11, R31.2
unnamed: C7.1, P5.10, R42.2
unnamed: C11.1, P5.8, R41.2
unnamed: C13.1, P5.7, R29.2
unnamed: C15.1, P5.5, R28.2
unnamed: C18.1, P5.4, R40.2
unnamed: C21.1, P5.3, R27.2
unnamed: J9.7, R2.1
unnamed: J9.5, R1.1
unnamed: J9.2, R9.2
unnamed: C24.1, P5.2, R39.2
unnamed: C27.1, P5.1, R26.2
unnamed: C9.1, P5.9, R30.2
unnamed: C4.1, P5.12, R43.2
unnamed: C25.1, P1.2, R18.2
unnamed: C16.1, P1.8, R33.2
unnamed: FB4.1, J10.1
unnamed: C38.2, D1.2, FB4.2, R48.2, U1.5
unnamed: J9.15, R5.1, R8.1
unnamed: J9.12, R12.2, R15.2
unnamed: J9.14, R13.2, R16.2
unnamed: J9.16, R14.2, R17.2
unnamed: C22.1, P1.3, R32.2
unnamed: C19.1, P1.4, R19.2
unnamed: FB1.2, J10.5
unnamed: J9.11, R3.1, R6.1
unnamed: J9.13, R4.1, R7.1
unnamed: C36.1, C37.1, FB5.1, J10.6, J10.7, J10.8, J10.9, J10.10, J10.11, J11.1, Q1.2, Q2.2
unnamed: Q2.1, R47.2
unnamed: FB3.2, Q2.3
unnamed: C37.2, FB3.1, J11.2
unnamed: C36.2, FB2.1, J11.5
unnamed: FB2.2, Q1.3
unnamed: Q1.1, R46.2
unnamed: D2.1, R53.2, U2.29
unnamed: C48.2, U2.85
unnamed: TP3.1, U2.66
unnamed: TP4.1, U2.67
unnamed: TP2.1, U2.61
unnamed: TP1.1, U2.60
unnamed: TP5.1, U2.68
unnamed: C52.1, U2.63, X2.3
unnamed: C51.1, U2.64, X2.1
unnamed: C46.2, C47.2, FB6.2, R53.1, U2.30
unnamed: P12.2, R52.2
unnamed: C50.1, U2.73, X1.1
unnamed: C49.1, U2.74, X1.4
unnamed: J15.5, R57.2, R60.2
unnamed: J15.2, R58.2, R59.1
unnamed: C68.1, U4.25
unnamed: C69.1, U4.27
unnamed: C71.1, U4.20
unnamed: C79.1, FB10.1, J14.5
unnamed: C77.2, FB11.1, J14.2
unnamed: C76.1, C77.1, C78.2, C79.2, FB12.1, J13.1, J14.1, J15.1
unnamed: C78.1, FB8.1, J13.5
unnamed: C76.2, FB9.1, J13.2
unnamed: C71.2, FB10.2, U5.3
unnamed: C72.2, FB11.2, R56.2, U5.4
unnamed: C69.2, FB9.2, U5.1
unnamed: C68.2, FB8.2, U5.6
unnamed: C65.2, C67.2, U4.18
unnamed: C66.2, C70.2, U4.24
unnamed: C72.1, U4.21
unnamed: R56.1, U4.19
unnamed: C61.2, C62.2, U4.29
unnamed: C63.2, C64.2, FB7.2, U4.26
unnamed: C57.2, U4.14
unnamed: C56.2, U4.16
unnamed: C55.2, U4.15
unnamed: C58.2, U4.13
unnamed: C60.2, U4.23
unnamed: C59.2, U4.22
unnamed: D3.1, R66.2
unnamed: C91.2, U6.23, X3.3
unnamed: J16.2, T1.11
unnamed: J16.4, J16.5, R76.2
unnamed: J16.1, T1.9
unnamed: J16.7, J16.8, R80.2
unnamed: C87.2, U7.3
unnamed: R65.1, U7.7
unnamed: C92.1, C93.1, C95.1, FB13.2, U7.12, U7.13, U7.14
unnamed: R79.2, R81.1, U8.12
unnamed: C94.2, U6.24, X3.1
unnamed: R75.2, T1.10
unnamed: R63.1, U6.14
unnamed: R66.1, U6.26
unnamed: C81.1, U6.1
unnamed: J16.6, T1.16
unnamed: J16.3, T1.14
unnamed: C102.1, U8.4
unnamed: C98.2, R71.2, R72.1, U8.9
unnamed: C85.1, U7.4
unnamed: R64.2, R77.1, U7.6, U8.6
unnamed: C80.2, R61.2, R62.1, U7.9
unnamed: R73.1, U8.7
unnamed: C96.1, C105.1, C106.1, FB15.2, U8.13, U8.14
unnamed: C103.2, U8.3
unnamed: C97.1, FB14.1, R68.2, R70.2, T1.7
unnamed: C99.1, R67.1, R69.1
unnamed: R68.1, T1.6, U6.16
unnamed: R69.2, T1.1, U6.12
unnamed: R67.2, T1.3, U6.13
unnamed: R70.1, T1.8, U6.17
unnamed: R74.2, T1.15
unnamed: C104.2, R74.1, R75.1, R76.1, R80.1
unnamed: C103.1, L2.2, U8.1, U8.2
unnamed: C87.1, L1.2, U7.1, U7.2
OSC_TMP: R20.1, U2.18
PS_SYNC: R64.1, U2.53
PTT_OUT: C32.2, R45.1, R47.1, U2.58
REFCLKO-MCLK: U2.98, U4.1
RX/TX: R18.1, U2.72
SCK1: U2.90, U4.8
SCK3: U2.77, U6.8
SCK4: U2.83, U3.6
SCL2: R25.1, U2.50
SDA2: R38.1, U2.49
SS1: U2.89, U4.9
SS3: U2.76, U6.9
SS4: U2.82, U3.1
TUNE_ENC_A: C1.1, R6.2, U2.7
TUNE_ENC_B: C2.1, R7.2, U2.9
TUNE_ENC_D: C29.2, R16.1, U2.8
USB_5V: C98.1, C100.1, C101.1, D1.1, L2.1, R71.1, U8.5
USB_D+: J10.3, U1.1, U2.57
USB_D-: J10.2, U1.6, U2.56
USB_FLAG: R78.1, U2.52, U8.8
USB_ID: J10.4, U1.3, U2.51
USB_VBUS: R48.1, U2.54
USB_VBUSON: R79.1, U2.20

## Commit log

2015-08-01 Update library list
    [Display_Board.sch, LCD and Encoders.sch]
2015-08-01 Remove Special Lib and add layout pdf files
    [Attenuator & PreAmp.sch, Audio Amps.sch, Band Pass Filter.sch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]
2015-08-02 Add Creative Commons License CC BY-SA 4.0
    [Attenuator & PreAmp.sch, Audio Amps.sch, Band Pass Filter.sch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]
2015-08-09 Add drawing Directory
    [Radio Housing_A.dwg]
2015-08-09 Add mechanical drawings
    [ODR-1 Mechanical_A.dwg]
2015-08-14 Update Lens in drawing, spreadsheet print set-up
    [2015001 ODR-1 Mechanical_A.dwg, OSC_Mixer_Board_BOM_A1.xls, Processor_Board BOM_A.xls]
2015-09-07 add red lines to schematic
2015-10-18 Drawing and red-line updates
    [2015001 ODR-1 Mechanical_A.dwg]
2016-01-03 Add Amp and Tuner Board Files
    [2015001 ODR-1 Mechanical_A.dwg, Amp_Tuner_Board.kicad_pcb, Amp_Tuner_Board.sch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]
2016-01-04 Add more to schematic
    [Amp_Tuner_Board.sch, Antenna_Tuner.sch, Interface.sch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]
2018-01-13 RF Power Amp Design Updates
    Minor Updates to RF Power Amp Design
    [Amp_Tuner_Board.sch, Antenna_Tuner.sch, Interface.sch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]
2018-01-14 Update Gitignore
    Add .tmp to gitignore, reprint RF power amp preliminary shematic.
